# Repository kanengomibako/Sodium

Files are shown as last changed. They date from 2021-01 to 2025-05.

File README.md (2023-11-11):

# Sodium
### STM32 Programmable Digital Effects Pedal
STM32マイコンを搭載した、プログラミング可能なデジタルエフェクターです。C言語またはC++で開発を行います。もちろんプログラム書き込み後は単体のエフェクターとして動作可能です。

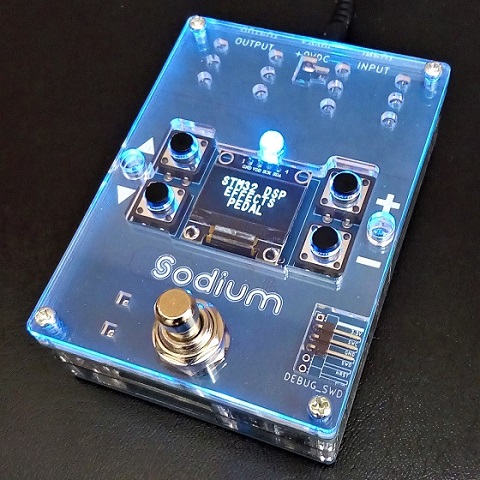
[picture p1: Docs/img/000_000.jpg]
Sodium_pic


### 別途必要なもの
- DC9V（センターマイナス）出力のACアダプターで、0.3A以上の電流出力が可能なもの
- PC（Windows、macOS、Linux いずれも可、64bit推奨）<br/>※ 32bit環境では使用できる開発ソフトが限られます。
- STM32対応のデバッガ（プログラム書き込みやデバッグを行う機器）<br/>
	→ [デバッガ購入について](Docs/005_デバッガ購入について.md)
- PCとデバッガを接続するUSBケーブル
- デバッガとSodium本体を接続するケーブル<br/>
	→ [コネクタ付コード 3P](https://akizukidenshi.com/catalog/g/gC-15384/) 等

### 各部の機能
- INPUT 端子：ギターや他の機器からの出力を接続します。
- OUTPUT 端子：アンプや他の機器の入力へ接続します。
- +9VDC 端子：ACアダプターを接続します。
- 各スイッチ：任意の機能をプログラミング可能です。初期プログラムの操作については[別ページ](Docs/000_初期プログラムについて.md)をご参照ください。
- Serial Wire Debug (SWD)接続ピン：デバッガのSWCLK、GND、SWDIOピンを、SodiumのSWC、GND、SWDピンへそれぞれ接続します。

### 資料
- [Rev.E 基板（2021年5月以降販売分）での主な変更点](Docs/006_Rev.E基板での主な変更点.md)
- [初期プログラムについて](Docs/000_初期プログラムについて.md)
- [デバッガ購入について](Docs/005_デバッガ購入について.md)
- [プログラム書き込み・デバッグ](Docs/001_プログラム書き込み・デバッグ.md)
- [サンプルプログラムについて](Docs/002_サンプルプログラムについて.md)
- [マイコンの機能設定](Docs/003_マイコンの機能設定.md)
- [プログラミング概要](Docs/004_プログラミング概要.md)
- [エフェクト種類管理（fx.cpp）について](Docs/100_エフェクト種類管理（fx.cpp）について.md)
- [エフェクトファイル（fx_○○.hpp）について](Docs/110_エフェクトファイル（fx_○○.hpp）について.md)
- [各エフェクト説明目次](Docs/200_各エフェクト説明目次.md)

| 主な仕様 |  |
| - | - |
| サンプリング周波数 | 44.1 kHz（48 kHz または 96 kHz に設定可能） |
| 内部演算 | 32ビット浮動小数点 |
| AD、DA変換 | 24 ビット |
| レイテンシ | 1.5 ミリ秒（初期プログラム実行時） |
| 最大入力レベル | 1.0 Vrms (+2.2 dBu) |
| 入力インピーダンス | 1 MΩ |
| 最大出力レベル | 1.35 Vrms (+4.8 dBu) |
| 出力インピーダンス | 1 kΩ |
| バイパス | バッファード・バイパス（バイパス音もAD/DA変換されます） |
| コントロール | 押しボタンスイッチ×4　フットスイッチ×1 |
| ディスプレイ | 有機ELディスプレイ　モノクロ128×64ドット |
| インジケーター | 3色LED（直径5mm） |
| 接続端子 | INPUT端子　OUTPUT端子　電源入力端子<br/>Serial Wire Debug (SWD)接続ピン |
| 消費電流 | 150 mA |
| 外形寸法 | 幅 73 mm × 奥行 107 mm × 高さ 46 mm<br/>（フットスイッチ部を除いた高さ 33 mm）<br/>※ 2021年1月販売分は高さ+2mm |
| 質量 | 240 g |

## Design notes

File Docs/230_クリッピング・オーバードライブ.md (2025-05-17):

# クリッピング・オーバードライブ

歪み系エフェクトに使うクリッピングについて、下記記事にまとめています。

- [歪みと波形・倍音その9（非線形性と歪み）](https://kanengomibako.github.io/pages/00209.html)

クリッピングに使いやすそうな関数を下図にまとめました。歪み始めや頭打ち部分の音量がそれぞれ違ってくるため、似たような形になるように適宜調整しています。（[GeoGebra](https://www.geogebra.org/) で作成）

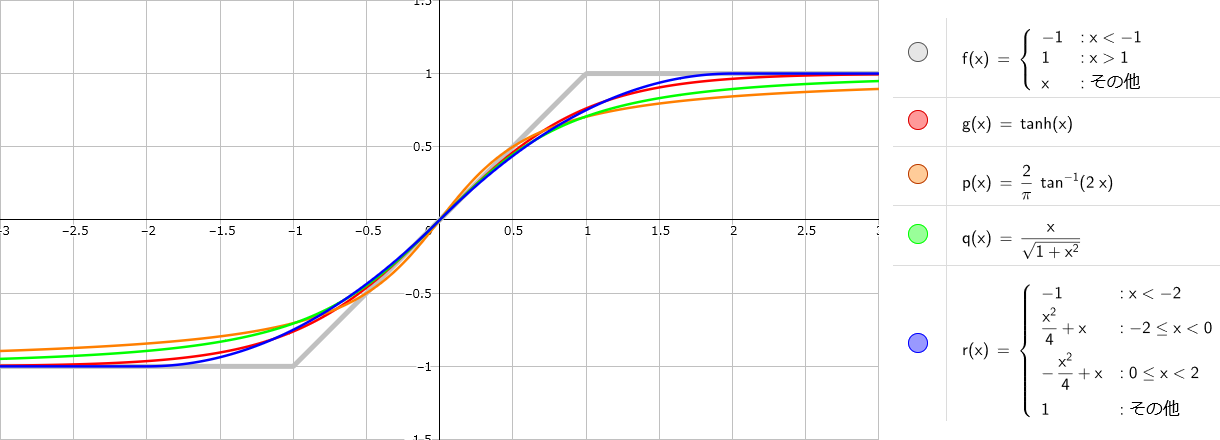
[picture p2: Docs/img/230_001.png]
graph


下記参考ページでは、tanh 関数を変形させた例が記載されています。

- [gDSP](http://gdsp.hf.ntnu.no/) - [The modified tanh() function](http://gdsp.hf.ntnu.no/lessons/3/18/)

---

[fx_overdrive.hpp](https://github.com/kanengomibako/Sodium/blob/main/Src/example/fx_overdrive.hpp) （オーバードライブ）のコード内容について説明します。

```c++
private:
  const string name = "OVERDRIVE";
  const uint16_t color = COLOR_RG; // 赤緑
  const string paramName[20] = {"LEVEL", "GAIN", "TREBLE", "BASS"};
  enum paramName {LEVEL, GAIN, TREBLE, BASS};
  float param[20] = {1, 1, 1, 1};
  const int16_t paramMax[20] = {100,100,100,100};
  const int16_t paramMin[20] = {  0,  0,  0,  0};
  const uint8_t paramNumMax = 4;

  signalSw bypass;
  hpf hpfFixed, hpfBass; // 出力ローカット、入力BASS調整
  lpf lpfFixed, lpfTreble; // 入力ハイカット、出力TREBLE調整
```
コントロールは全て0～100としました。下部で固定値のフィルタとトーン調整用フィルタを準備しています。<br>
<br>

```c++
  virtual void setParam()
  {
    static uint8_t count = 0;
    count = (count + 1) % 10; // 負荷軽減のためパラメータ計算を分散させる
    switch(count)
    {
      case 0:
        param[LEVEL] = logPot(fxParam[LEVEL], -50.0f, 0.0f);  // LEVEL -50～0 dB
        break;
      case 1:
        param[GAIN] = logPot(fxParam[GAIN], 20.0f, 60.0f); // GAIN 20～60 dB
        break;
      case 2:
        param[TREBLE] = 10000.0f * logPot(fxParam[TREBLE], -30.0f, 0.0f); // TREBLE LPF 320～10k Hz
        break;
      case 3:
        param[BASS] = 2000.0f * logPot(fxParam[BASS], 0.0f, -20.0f); // BASS HPF 200～2000 Hz
        break;
      case 4:
        lpfTreble.set(param[TREBLE]);
        break;
      case 5:
        hpfBass.set(param[BASS]);
        break;
      case 6:
        lpfFixed.set(4000.0f); // 入力ハイカット 固定値
        break;
      case 7:
        hpfFixed.set(30.0f); // 出力ローカット 固定値
        break;
      default:
        break;
    }
  }
```
`logPot`関数は [lib_calc.hpp](https://github.com/kanengomibako/Sodium/blob/main/Src/example/lib_calc.hpp) にある通り、パラメータ整数値 0 ～ 100 を dB 倍率へ変換します。この関数はゲインだけでなく、フィルタの周波数についても調整しやすいです。上記`BASS`のハイパスフィルタ周波数の場合は 0 dB（1倍）～ -20 dB（0.1倍）で計算され、2000 ～ 200 Hz で変化するという具合です。

固定値のフィルタ周波数設定（`set`）は何度も実行する必要はないため、`init`関数内に記載しても問題ありません。<br>
<br>

```c++
  virtual void process(float xL[], float xR[])
  {
    setParam();

    for (uint16_t i = 0; i < BLOCK_SIZE; i++)
    {
      float fxL = xL[i];

      fxL = hpfBass.process(fxL);   // 入力ローカット BASS
      fxL = lpfFixed.process(fxL);  // 入力ハイカット 固定値
      fxL = param[GAIN] * fxL;      // GAIN
      fxL = atanf(fxL + 0.5f);      // arctanによるクリッピング、非対称化
      fxL = hpfFixed.process(fxL);  // 出力ローカット 固定値 直流カット
      fxL = lpfTreble.process(fxL); // 出力ハイカット TREBLE
      fxL = param[LEVEL] * fxL;     // LEVEL

      xL[i] = bypass.process(xL[i], fxL, fxOn);
    }
  }
```
HPF → LPF → GAIN → クリッピング → HPF → LPF → LEVEL という流れです。クリッピングは直流成分を加えて非対称としましたが、直流成分を増幅しないように、直後にハイパスフィルタを入れます。

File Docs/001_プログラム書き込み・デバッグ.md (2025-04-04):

# プログラム書き込み、デバッグ

例として、初期プログラムの書き込み、デバッグまでの手順を説明します。

***

### 1. STM32CubeIDEのインストール
STM32マイコンの統合開発環境として、[STM32CubeIDE](https://www.st.com/ja/development-tools/stm32cubeide.html)をインストールします（32bitのOSには非対応）。ダウンロードに[myST](https://www.st.com/content/st_com/ja.html)への登録が必要です。初回起動時にWorkspace（作業フォルダ）を設定しますが、パスに全角文字が入らないようにしておきます。STM32CubeIDE未経験の方は、練習としてNucleo Boardを使ったLチカを先にされておくことをお勧めします。

- 参考ページ → [STM32 Nucleo STM32F303K8でLチカ & STM32CubeIDEで開発](https://ameblo.jp/denshi-1996/entry-12806626635.html)

***

### 2. 新規プロジェクト作成
- STM32CubeIDEを起動、File → New → STM32 Project
- Part Number に「F722RC」と入力 → STM32F722RC を選択 → Next（※ [Rev.E 基板](006_Rev.E基板での主な変更点.md)の場合、F722RE）
- Project Name に「Sodium_test」と入力 → Finish
- 自動で開かれる Sodium_test.ioc は閉じる

※ 初回はデータのダウンロード等があるため時間がかかります。

***

### 3. 必要なファイルのダウンロード
下記URLからzipファイルをダウンロード・展開し、出てきた8つのファイルを移動させます。
- [https://github.com/kanengomibako/Sodium/raw/main/Src/test/Sodium_test.zip](https://github.com/kanengomibako/Sodium/raw/main/Src/test/Sodium_test.zip)

	- Sodium_test.ioc → プロジェクトフォルダ内の同名ファイルに上書き
	- main.c → Core/Src フォルダ内の同名ファイルに上書き
	- user_main.c　fonts.c　ssd1306.c → Core/Src フォルダへ
	- user_main.h　fonts.h　ssd1306.h → Core/Inc フォルダへ

ディスプレイ用ライブラリは下記リポジトリのものを利用しています。
- [https://github.com/4ilo/ssd1306-stm32HAL](https://github.com/4ilo/ssd1306-stm32HAL)

***

### 4. コード出力、ビルド
- Sodium_test.ioc を開き、歯車アイコンをクリックしてコード出力

※ バージョンが違うといったメッセージが表示された場合は、「Migrate」を選択します。

- 金槌アイコンをクリックしてビルド開始

***

### 5. デバッガの接続、デバッグ
- デバッガのSWCLK、GND、SWDIOピンを、SodiumのSWC、GND、SWDピンへそれぞれ接続

▼ Nucleo Board（Nucleo-64タイプ）を使う場合（左上のジャンパーを外しておく）
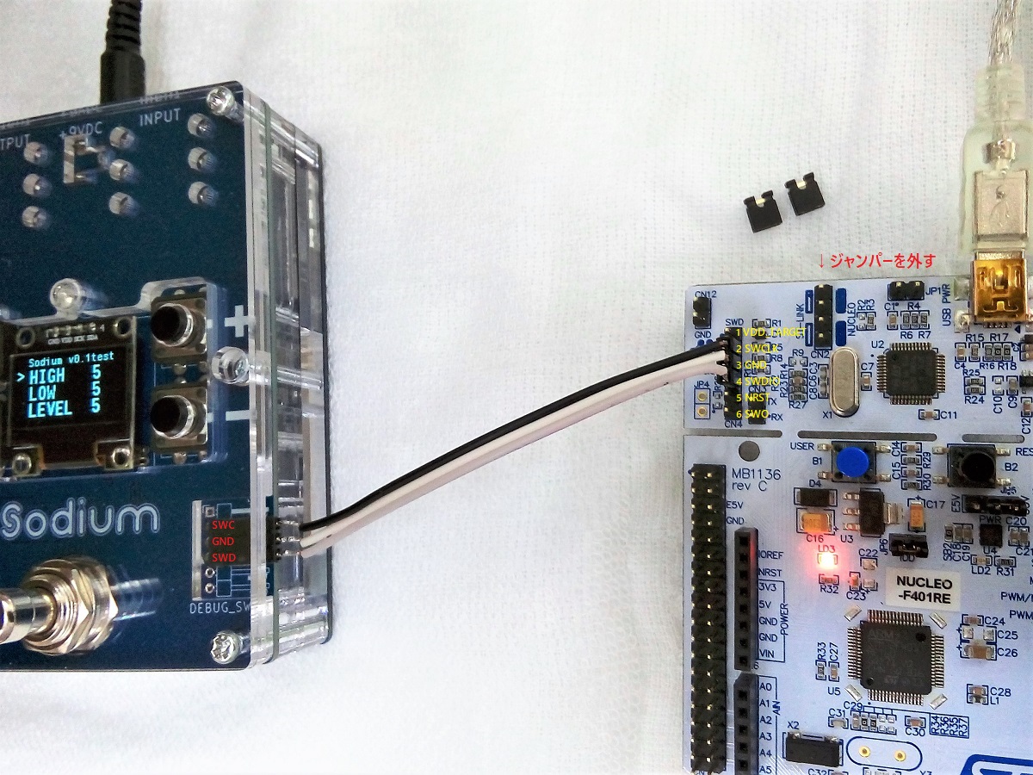
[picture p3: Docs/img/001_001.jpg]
デバッガーの接続
  

- 虫アイコンをクリック → 設定ウィンドウが2種類出てくるが、両方ともそのままOK

プログラムが書き込まれ、デバッグが開始されます。デバッグ画面では動作開始、一時停止等の操作を行うことができます。

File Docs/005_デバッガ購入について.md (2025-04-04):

# デバッガ購入について

### [Nucleo Board](https://www.st.com/ja/evaluation-tools/stm32-nucleo-boards.html)

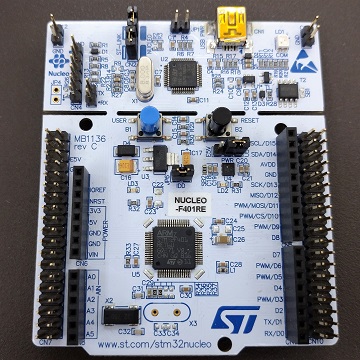
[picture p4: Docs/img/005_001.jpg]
Nucleo
 

STマイクロの低価格なマイコンボードです。デバッガが上部についており、切り込み部分から切り離して使うこともできます。様々な種類がありますが、安いもので問題ありません（USBコネクターの種類に注意）。他にもデバッガとして使えるものに[Discovery Kit](https://jp.rs-online.com/web/p/microcontroller-development-tools/7587554)、[STLINK-V3MINIE](https://akizukidenshi.com/catalog/g/g118187/)、[ST-LINK/V2](https://jp.rs-online.com/web/p/chip-programmers/7141701)、[STLINK-V3SET](https://akizukidenshi.com/catalog/g/gM-14361/)があります。

＜参考価格＞（2025年4月4日時点）

秋月電子へのリンクですが、RSコンポーネンツ等でも購入できます。

[NUCLEO-F103RB](https://akizukidenshi.com/catalog/g/g107724/) ￥2,200　[コネクター付コード 3P](https://akizukidenshi.com/catalog/g/gC-15384/) ￥60　[両端ロングピンヘッダー 1×6](https://akizukidenshi.com/catalog/g/g109055/) ￥20　[USBケーブル Type-Aオス⇔ミニBオス 1.5m](https://akizukidenshi.com/catalog/g/g117014/) ￥100

---

### ST-LINK V2 互換品

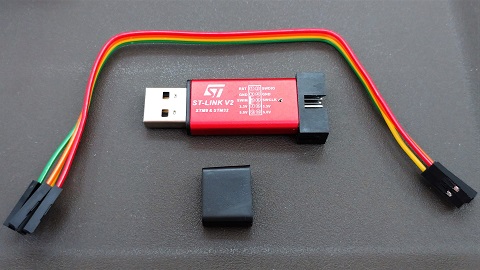
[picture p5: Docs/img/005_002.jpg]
stlc
 

AmazonやAliExpressで販売されている、低価格でコンパクトなST-LINK互換品です。~~十数個買ってみましたが特に問題なく使えたので、とにかく安く済ませたい場合はこちらで大丈夫だと思います。~~**最新のSTM32CubeIDE（1.13.2）ではファームウェアのアップグレードができず、使えなくなりました。内蔵マイコンの種類によってはアップグレードできるものがありますが、購入しない方が無難です。

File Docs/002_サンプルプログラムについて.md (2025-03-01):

# サンプルプログラムについて

サンプルプログラムの導入手順と操作方法を説明します。

※ 予期せぬエラーが発生する可能性があります。音量に充分注意して下さい。

（STM32CubeIDEのバージョン：1.17.0）

***

### 1. STM32CubeIDE 新規プロジェクト作成
- STM32CubeIDEを起動、File → New → STM32 Project
- Part Number に「F722RC」と入力 → STM32F722RC を選択 → Next（※ [Rev.E 基板](006_Rev.E基板での主な変更点.md)の場合、F722RE）
- Project Name に「Sodium_example」と入力
- Targeted Language に C++ を選択 → Finish
- 自動で開かれる Sodium_example.ioc は閉じる

***

### 2. 必要なファイルのダウンロード
下記URLからzipファイルをダウンロード・展開し、出てきたファイルを移動させます。
- [https://github.com/kanengomibako/Sodium/raw/main/Src/example/Sodium_example_v1.9.zip](https://github.com/kanengomibako/Sodium/raw/main/Src/example/Sodium_example_v1.9.zip)
	- Sodium_example.ioc　STM32F722RCTX_FLASH.ld → プロジェクトフォルダ内の同名ファイルに上書き（※ [Rev.E 基板](006_Rev.E基板での主な変更点.md)の場合、STM32F722RETX_FLASH.ld）
		- Sodium_example.ioc を開き、歯車アイコンをクリックしてコード出力	
	- .cファイル　.cppファイル → Core/Src フォルダへ（ main.c は上書き）
	- .hファイル　.hppファイル → Core/Inc フォルダへ
- ビルドして書き込みを行うと、数種類のエフェクトが入ったプログラムが実行できます。
- common.h を編集すると各種機能や時間設定等を行うことができます。
- fx.cpp を編集すると有効化するエフェクトを選択できます。

***

### 3. 操作方法
- 左上スイッチ（▲）
	- 短押し：カーソルを前へ移動
	- 長押し：エフェクト切替
	- 左下スイッチと同時に長押し：現在選択しているエフェクトのパラメータを保存
- 左下スイッチ（▼）
	- 短押し：カーソルを次へ移動
	- 長押し：エフェクト切替
	- 左上スイッチと同時に長押し：現在選択しているエフェクトのパラメータを保存
- 右上スイッチ（＋）
	- 短押し：パラメータ増加
	- 長押し：パラメータを10ずつ増加
	- 右下スイッチと同時に短押し：パラメータを最大値と最小値の中間の値へ変更
	- 左上スイッチと同時に短押し：パラメータを最大値へ変更
- 右下スイッチ（ー）
	- 短押し：パラメータ減少
	- 長押し：パラメータを10ずつ減少
	- 右上スイッチと同時に短押し：パラメータを最大値と最小値の中間の値へ変更
	- 左下スイッチと同時に短押し：パラメータを最小値へ変更
- フットスイッチ
	- 短押し：エフェクトのオン／オフ切替（オン時LED点灯）
	- 長押し：タップテンポモードへ、さらに長く押したままにするとチューナーモードへ（もう一度長押しで通常モードに戻る）
- その他
	- 保存データ全消去：左上スイッチ・右下スイッチ・フットスイッチを押しながら起動

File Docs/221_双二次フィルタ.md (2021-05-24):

# 双二次フィルタ

双二次フィルタ（BiQuad フィルタ）はデジタルフィルタの中で特に使いやすいフィルタです。イコライザやローパスフィルタ、ハイシェルフフィルタ等、様々なタイプのフィルタを使うことができます。入力と出力の関係は次の式で表されます。

- y<sub>n</sub> = (b<sub>0</sub>/a<sub>0</sub>) x<sub>n</sub> + (b<sub>1</sub>/a<sub>0</sub>) x<sub>n-1</sub> + (b2/a<sub>0</sub>) x<sub>n-2</sub> - (a<sub>1</sub>/a<sub>0</sub>) y<sub>n-1</sub> - (a<sub>2</sub>/a<sub>0</sub>) y<sub>n-2</sub>

[1次フィルタ](220_1次ローパス・ハイパスフィルタ.md)の時と同様に、前回・前々回の入出力データを使います。フィルタのタイプに応じて係数 a<sub>1</sub>、b<sub>1</sub> 等の計算式が変わります。

【参考ページ】
- [C++でVST作り](https://vstcpp.wpblog.jp/) - [簡単なデジタルフィルタの実装](https://vstcpp.wpblog.jp/?page_id=523)
	
	周波数特性の図もあり、非常に素晴らしいサイトです。
---

[lib_filter.hpp](https://github.com/kanengomibako/Sodium/blob/main/Src/example/lib_filter.hpp) のコード内容について説明します。

- 三角関数等の計算

```c++
inline float bqSinOmega(float fc)
{
//（中略）
}

inline float bqCosOmega(float fc)
{
//（以下略）
```
3次関数の近似式を使用しています。sinf 関数より少し速い程度です。<br>
<br>

- フィルタタイプ
```c++
enum BQFtype
{
  OFF, // No Filter (default)
//（中略）
  APF, // All Pass Filter
};
```
各フィルタタイプの定義です。後々出てくる係数設定の場合分けに使用します。<br>
<br>

- 実行
```c++
  float process(float x) // BiQuadフィルタ 実行
  {
    float y = b0 * x + b1 * x1 + b2 * x2 - a1 * y1 - a2 * y2;
    x2 = x1;
    x1 = x;
    y2 = y1;
    y1 = y;
    return y;
  }
```
`a0` が式に入っていないのは、係数計算の時に `b0` 等に含めて計算しているためです。`x1`、`x2`、`y1`、`y2` に過去のデータを保存しておき、次回呼び出し時の計算で使用します。<br>
<br>

- 係数設定
```c++
  void setCoef(int type, float fc, float q_bw, float gain) // 係数設定
  {
    switch(type)
    {
    case PF:
      setPF(fc, q_bw, gain);
      break;
//（中略）
    }
  }

  // 各フィルタタイプ 係数設定
  void setPF(float fc, float q, float gain)
  {
    float alpha = bqAlphaQ(fc,q);
    float cos = bqCosOmega(fc);
    float A = bqA(gain);

    float norm = 1.0f / (1.0f + alpha / A);
    a1 = (-2.0f * cos) * norm;
    a2 = ( 1.0f - alpha / A) * norm;
    b0 = ( 1.0f + alpha * A) * norm;
    b1 = a1;
    b2 = ( 1.0f - alpha * A) * norm;
  }
//（以下略）
```
フィルタのタイプを自由に変更したい場合、`setCoef`関数でタイプ別に係数設定を行えます（通常はタイプ固定で`setPF`関数等を直接実行します）。`norm` は 1 /  a<sub>0</sub> にあたるもので、あらかじめ他の係数と一緒に計算しています。帯域幅（BW）を使うと計算負荷が重いため、全てQ値を使った設定です。<br>
<br>

---

[fx_filter.hpp](https://github.com/kanengomibako/Sodium/blob/main/Src/example/fx_filter.hpp) は、音量調整と双二次フィルタをかけるエフェクトです。コード内容について説明します。

```c++
private:
  const string name = "BQ FILTER";
  const uint16_t color = COLOR_BG; // 青緑
  const string paramName[20] = {"LV", "TYPE", "Fc", "Q", "dB"};
  enum paramName {LEVEL, TYPE, FREQ, Q, GAIN};
  float param[20] = {1, 1, 1, 1, 1};
  const int16_t paramMax[20] = { 20,  8,999, 99, 15};
  const int16_t paramMin[20] = {-20,  0,  2,  1,-15};
  const uint8_t paramNumMax = 5;

  const string typeName[9] = {"OFF","PF","LSF","HSF","LPF","HPF","BPF","NF","APF"};
  signalSw bypass;
  biquadFilter bqf1;
```
フィルタのタイプを変更できるようにし、タイプ名表示用に文字列`typeName`を準備しています。<br>
<br>

```c++
  virtual void setParam()
  {
    static uint8_t count = 0;
    count = (count + 1) % 10; // 負荷軽減のためパラメータ計算を分散させる
    switch(count)
    {
      case 0:
        param[LEVEL] = dbToGain(fxParam[LEVEL]); // LEVEL -20...+20 dB
        break;
      case 1:
        param[TYPE] = (float)fxParam[TYPE]; // フィルタタイプ
        break;
      case 2:
        param[FREQ] = (float)fxParam[FREQ] * 10.0f; // フィルタ 周波数 20...9990 Hz
        break;
      case 3:
        param[Q] = (float)fxParam[Q] * 0.1f; // フィルタ Q 0.1...9.9
        break;
      case 4:
        param[GAIN] = (float)fxParam[GAIN]; // フィルタ GAIN -15...+15 dB
        break;
      case 5:
        bqf1.setCoef(fxParam[TYPE], param[FREQ], param[Q], param[GAIN]); // フィルタ 係数設定
        break;
      default:
        break;
    }
  }
```
`setCoef`関数でタイプ別に係数設定を更新します。整数型が都合がよいため`param[TYPE]`ではなく`fxParam[TYPE]`の方を使っています。<br>
<br>

```c++
  virtual void process(float xL[], float xR[])
  {
    setParam();

    for (uint16_t i = 0; i < BLOCK_SIZE; i++)
    {
      float fxL = xL[i];
      fxL = bqf1.process(fxL); // フィルタ実行
      fxL = param[LEVEL] * fxL; // LEVEL
      xL[i] = bypass.process(xL[i], fxL, fxOn);
    }
  }
```
エフェクト用データ`fxL`に、`process`関数を実行します。

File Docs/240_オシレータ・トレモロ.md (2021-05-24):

# オシレータ・トレモロ

揺れ系エフェクトに使う LFO（Low Frequency Oscillator）の実装について説明します。下図は周波数 f（周期 1 / f ）、出力 0 ～ 1 ののこぎり波です。

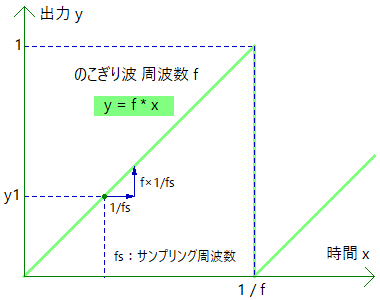
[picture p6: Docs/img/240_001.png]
graph
 

直線の傾きは 1 ÷ ( 1 / f ) で f となります。ある時点の出力 y1 から、次のサンプル時点までに経過する時間は 1 / fs です。増加する出力は傾き f × ( 1 / fs ) で f / fs となります。[lib_osc.hpp](https://github.com/kanengomibako/Sodium/blob/main/Src/example/lib_osc.hpp) の`sawWave`クラスでは下記コードです。

```c++
  float output()
  {
    float y = y1 + freq / SAMPLING_FREQ;
    if (y > 1) y = y - 1.0f;
    y1 = y; // 前回出力値を記録
    return y;
  }
```

前回の出力値を記録しておき、 f / fs を足して出力します。出力が 1 を超えた時点で 1 を引いてリセットします（0 にすると周期が少しズレてしまいます）。y1 の初期値を変更しておけば、位相を変えることができます。

正弦波と三角波（`sineWave`、`triangleWave`クラス）はのこぎり波を利用して実装しています。低い周波数だけでなく可聴域の音声信号も出力可能です。[fx_oscillator.hpp](https://github.com/kanengomibako/Sodium/blob/main/Src/example/fx_oscillator.hpp) はエフェクトではなく波形テスト用の発振器です。

---

[fx_tremolo.hpp](https://github.com/kanengomibako/Sodium/blob/main/Src/example/fx_tremolo.hpp) （トレモロ）のコード内容について説明します。

```c++
  virtual void setParam()
  {
    static uint8_t count = 0;
    count = (count + 1) % 10; // 負荷軽減のためパラメータ計算を分散させる
    switch(count)
    {
      case 0:
        param[LEVEL] = logPot(fxParam[LEVEL], -20.0f, 20.0f);  // LEVEL -20～20 dB
        break;
      case 1:
        param[RATE] = 0.01f * (105.0f - (float)fxParam[RATE]); // RATE 周期 1.05～0.05 秒
        break;
      case 2:
        param[DEPTH] = (float)fxParam[DEPTH] * 0.1f; // DEPTH -10～10 dB
        break;
      case 3:
        param[WAVE] = logPot(fxParam[WAVE], 0.0f, 50.0f); // WAVE 三角波～矩形波変形
        break;
      case 4:
        tri.set(1.0f / param[RATE]); // 三角波 周波数設定
        break;
      default:
        break;
    }
  }
```
三角波で音量を最大 ±10 dB 揺らします。WAVE コントロールは、揺れに使う波形を矩形波に変形させます。<br>
<br>

```c++
  virtual void process(float xL[], float xR[])
  {
    setParam();

    for (uint16_t i = 0; i < BLOCK_SIZE; i++)
    {
      float fxL = xL[i];

      float gain = 2.0f * tri.output() - 1.0f; // LFO -1～1 三角波
      gain = param[WAVE] * gain;     // 三角波を増幅
      if (gain > 1.0f) gain = 1.0f;  // クリッピング（矩形波に近い形へ）
      if (gain < -1.0f) gain = -1.0f;
      gain = param[DEPTH] * gain; // DEPTH -10～10 dB

      fxL = dbToGain(gain) * fxL; // 音量を揺らす
      fxL = param[LEVEL] * fxL;   // LEVEL

      xL[i] = bypass.process(xL[i], fxL, fxOn);
    }
  }
```
LFO の出力はわかりやすいように -1 ～ 1 の範囲としました。矩形波の音量変化が大きすぎる場合、「プチッ」というノイズが聞こえる場合があります。クリッピングに tanh 等の関数を用いてみるのもよいかもしれません。

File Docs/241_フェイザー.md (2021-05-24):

# フェイザー

位相を変化させた音と原音を足し合わせると、特定の周波数が減衰し谷となるノッチフィルタのような特性が得られます。この谷の周波数を揺らすエフェクトがフェイザーです。位相を変化させるには、オールパスフィルタ（APF）を使用します。APF の数 2 個につき谷の数は 1 個となります。

---

[fx_phaser.hpp](https://github.com/kanengomibako/Sodium/blob/main/Src/example/fx_phaser.hpp) （フェイザー）のコード内容について説明します。[フィルタ](220_1次ローパス・ハイパスフィルタ.md)と [LFO](240_オシレータ・トレモロ.md) の組み合わせです。

```c++
private:
  const string name = "PHASER";
  const uint16_t color = COLOR_R; // 赤
  const string paramName[20] = {"LEVEL", "RATE", "STAGE"};
  enum paramName {LEVEL, RATE, STAGE};
  float param[20] = {1, 1, 1};
  const int16_t paramMax[20] = {100,100,  6};
  const int16_t paramMin[20] = {  0,  0,  1};
  const uint8_t paramNumMax = 3;

  signalSw bypass;
  triangleWave tri;
  apf apfx[12];
```
STAGE（段数）パラメータでフィルタの個数を変更できるようにします。APF は for ループで使用するため、配列でインスタンス生成しています（下記コード参照）。<br>
<br>

```c++
  virtual void process(float xL[], float xR[])
  {
    setParam();

    for (uint16_t i = 0; i < BLOCK_SIZE; i++)
    {
      float fxL = xL[i];

      float lfo = 20.0f * tri.output();    // LFO 0～20 三角波
      float freq = 200.0f * dbToGain(lfo); // APF周波数 200～2000Hz 指数的変化

      for (uint8_t j = 0; j < (uint8_t)param[STAGE]; j++) // 段数分APF繰り返し
      {
        apfx[j].set(freq);          // APF周波数設定
        fxL = apfx[j].process(fxL); // APF実行
      }

      fxL = 0.7f * (xL[i] + fxL); // 原音ミックス、音量調整
      fxL = param[LEVEL] * fxL;   // LEVEL

      xL[i] = bypass.process(xL[i], fxL, fxOn);
    }
  }
```
周波数は指数関数的変化がよいため、`dbToGain`を使いました。for ループを使って繰り返し APF をかけ、原音ミックスします。音量は LEVEL 50 でエフェクトオフと同じくらいになるよう調整しています。

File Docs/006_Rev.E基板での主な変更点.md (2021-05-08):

# Rev.E 基板での主な変更点

2021年5月販売分より、基板のバージョンが Rev.D → Rev.E となっています。

▼ OUTPUTジャック側から中を除くと、「Rev.E」の文字が見えます。

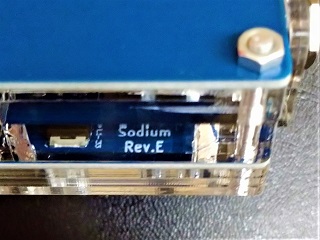
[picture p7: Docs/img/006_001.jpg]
E
 

---

- ### F722R"C" → F722R"E"

	入手性の問題から、マイコンが STM32F722RCT6 → STM32F722RET6 となり、フラッシュメモリの容量が 256 kB から 512 kB へ増えました。他の説明文書内の F722RC という記述は、適宜 F722RE に読み替えていただくようお願いします。互換性維持のため、STM32F722RETX_FLASH.ld ファイル内ではセクタ5以降の全領域をデータ保存用として設定してあります。
	
	※ 誤って F722RC のプログラムをそのまま書き込んでも動作に問題はありません。

---

- ### 赤LED 接続ピン追加

	赤LED をマイコンの PA7 ピンに接続しています。PWM を利用して明るさを調整する場合は、PA7 ピンが使えます。従来通り PA4 ピンにも接続したままなので、旧基板用プログラムの互換性についての問題はありません。

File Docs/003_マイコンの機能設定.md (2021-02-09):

# マイコンの機能設定

iocファイルを開くと、STM32マイコンのピンや機能の設定を行うことができます。Sodiumでの設定内容について説明します。

***

### 1. システム
- 処理高速化のためARTアクセラレータ、Dキャッシュを有効化
	- System Core → CORTEX_M7 → Cortex Interface Settings
		- ART ACCELERATOR : Enabled
		- CPU DCache : Enabled
- クロック源として外部水晶振動子を使用
	- System Core → RCC → High Speed Clock (HSE) [Crystal/Ceramic Resonator]
- デバッガ接続
	- System Core → SYS → Debug [Serial Wire]

***

### 2. OLEDディスプレイ接続（I2C）

- I2C1を有効化
	- Connectivity → I2C1 → I2C [I2C]
	- Parameter Settings タブ → I2C Speed Mode [Fast Mode]
	- PB6、PB7 を使うようにピン設定
	
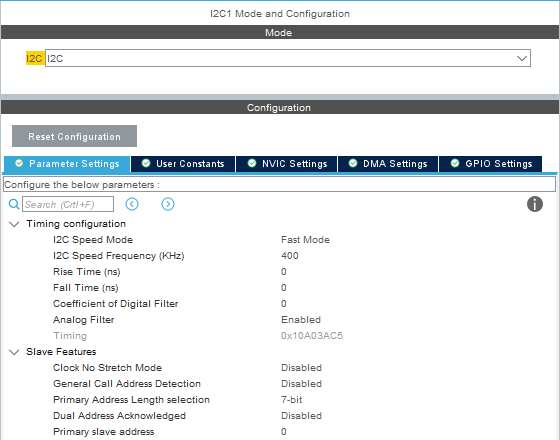
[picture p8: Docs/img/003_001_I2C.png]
I2C1
	 

***

### 3. オーディオコーデック接続（I2S）
- I2S2を有効化
	- Multimedia → I2S2 → MODE → Mode [Half-Duplex Master]　Master Clock Output にチェック
	- Parameter Settings タブ
		- Data and Frame Format [32 Bits Data on 32 Bits Frame]
		- Selected Audio Frequency [44 KHz]
		
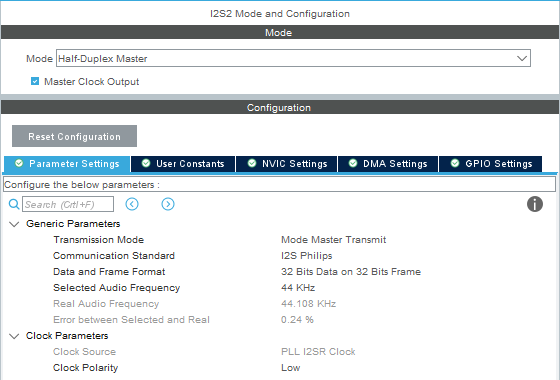
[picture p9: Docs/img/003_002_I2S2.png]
I2S2
		 
		
	- DMA Settings タブ → Addボタンで追加 → DMA Request [SPI2_TX]  Priority [Very High]
		- Mode : Circular
		- Data Width (Peripheral) : Half Word
		- Data Width (Memory) : Half Word
		
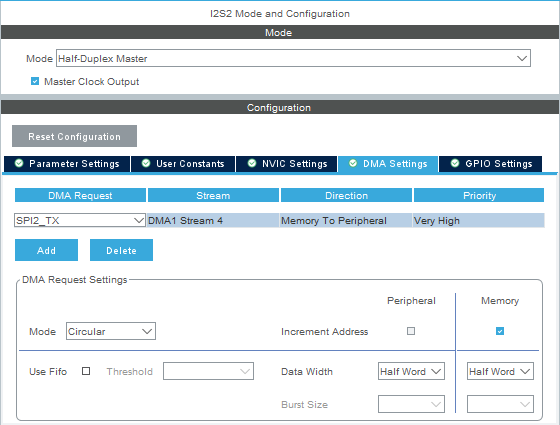
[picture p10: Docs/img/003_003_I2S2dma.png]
I2S2dma
		 
		
	- PB12、PB13、PB15、PC6 を使うようにピン設定
- I2S3を有効化
	- Multimedia → I2S3 → MODE → Mode [Half-Duplex Slave]
	- Parameter Settings タブ
		- Transmission Mode [Mode Slave Receive]
		- Data and Frame Format [32 Bits Data on 32 Bits Frame]
		- Selected Audio Frequency [44 KHz]
		
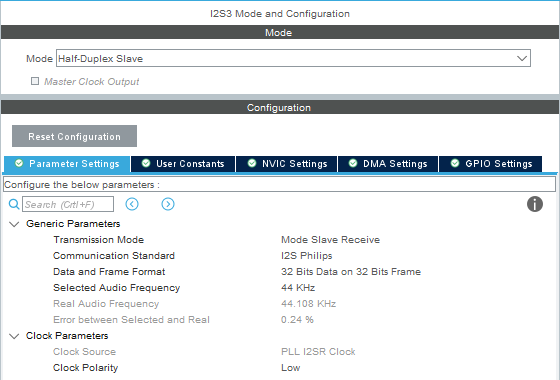
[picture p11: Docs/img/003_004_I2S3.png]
I2S3
		 
		
	- DMA Settings タブ → Addボタンで追加 → DMA Request [SPI3_RX]  Priority [Very High]
		- Mode : Circular
		- Data Width (Peripheral) : Half Word
		- Data Width (Memory) : Half Word
		
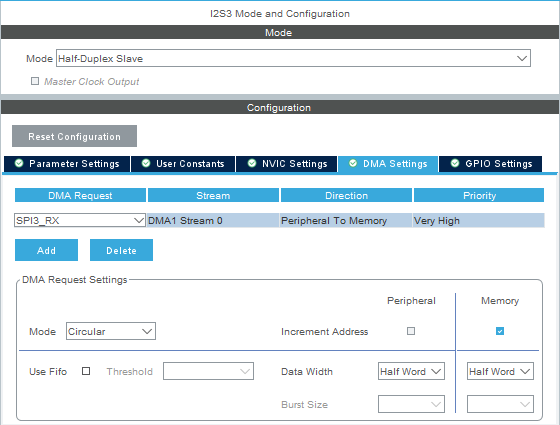
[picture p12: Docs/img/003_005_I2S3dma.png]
I2S3dma
		 
		
	- PA15、PC10、PC12 を使うようにピン設定

***

### 4. クロック
- Clock Configration タブで下図の通り設定

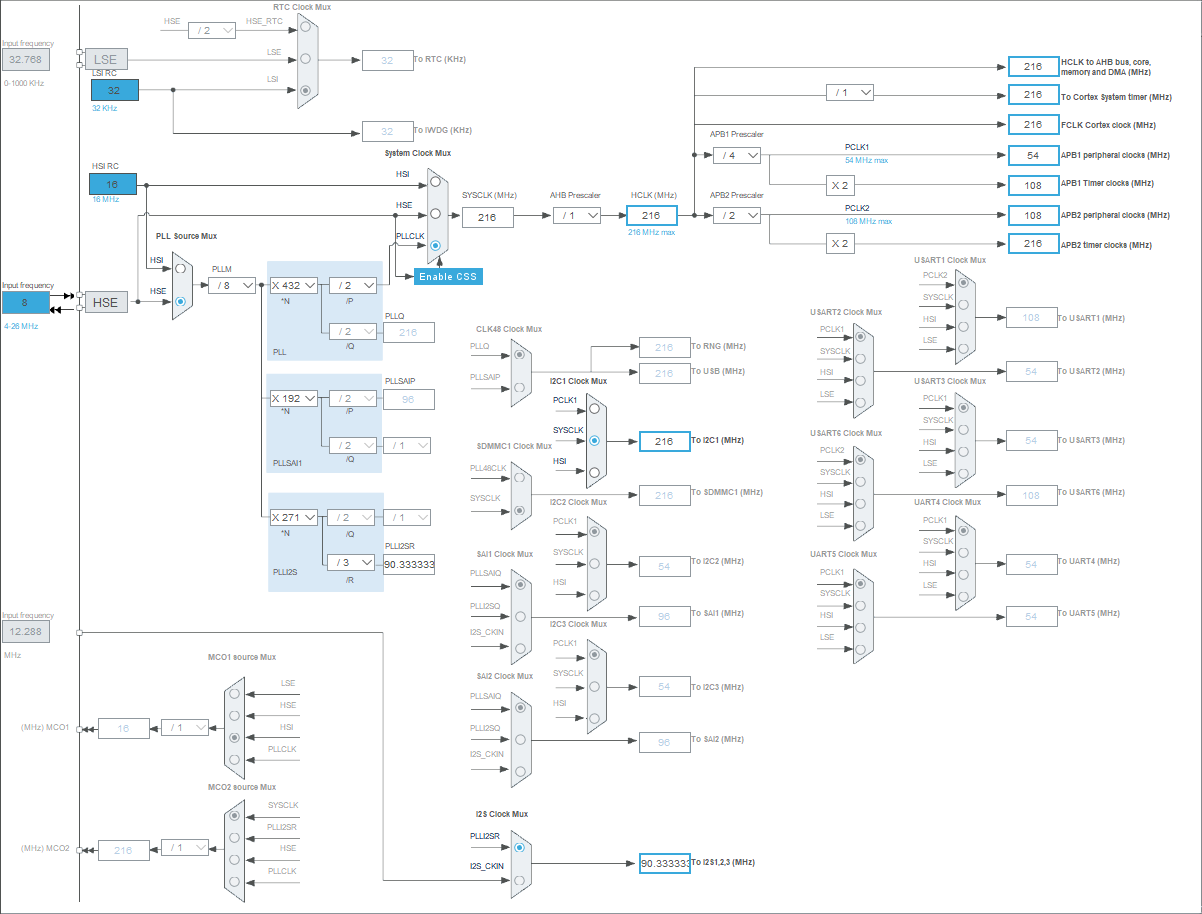
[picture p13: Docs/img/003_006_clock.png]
clock
 

実際のオーディオサンプリングレートは、I2Sクロックを2の累乗数で割った数となるため、90.333 MHz ÷ 2048 ＝ 44108.07 Hz です。44.1kHzから少しズレますが、プログラム上の定義をこの値にすれば実用上問題はありません（#define SAMPLING_FREQ 44108.07f）。

オーディオサンプリングレートを48kHzや96kHzにする場合は、PLLI2Sを [×295] [/3] とすると誤差が少ないです（98.333 MHz ÷ 2048 ＝ 48014.32 Hz）。

***

### 5. スイッチ・LED（GPIO）
- Pinout viewで入力ピン（PA1、PB0、PB1、PB4、PB5）、出力ピン（PA4、PA5、PA6、PB11）を設定

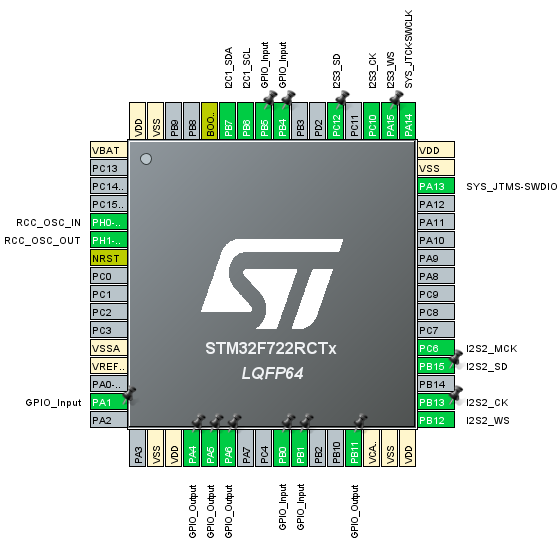
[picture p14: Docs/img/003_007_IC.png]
IC
 

- System Core → GPIO から入力ピンのプルアップとユーザーラベルを設定

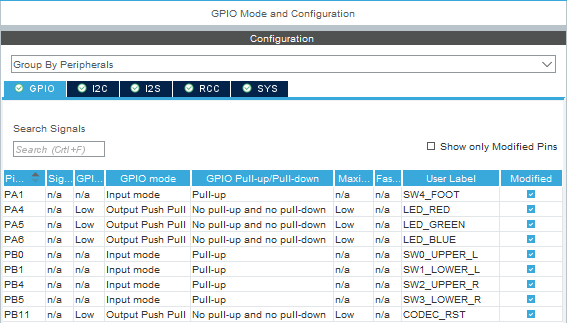
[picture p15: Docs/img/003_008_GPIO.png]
GPIO
 

ユーザーラベルを入力しておくと、main.h に定義が自動出力されます。（例：#define SW4_FOOT_Pin GPIO_PIN_1）

- ユーザーラベル一覧 
	- PA1	SW4_FOOT
	- PA4	LED_RED
	- PA5	LED_GREEN
	- PA6	LED_BLUE
	- PB0	SW0_UPPER_L
	- PB1	SW1_LOWER_L
	- PB4	SW2_UPPER_R
	- PB5	SW3_LOWER_R
	- PB11	CODEC_RST

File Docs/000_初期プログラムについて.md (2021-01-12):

# 初期プログラムについて

動作確認用初期プログラムとして、高音域・低音域・音量を調整するエフェクトが入っています。変更したパラメータを記憶する機能はありません。

### 起動時
ディスプレイが真っ白になり、LEDが赤、緑、青の順に点灯した後、エフェクト操作画面に切り替わります。

### スイッチ操作
- 左上スイッチ（▲）
	- 短押し：カーソル（＞）を上へ移動
	- 長押し：ディスプレイ上部に「SW0 LONG PUSH」と表示
- 左下スイッチ（▼）
	- 短押し：カーソル（＞）を下へ移動
	- 長押し：ディスプレイ上部に「SW1 LONG PUSH」と表示
- 右上スイッチ（＋）
	- 短押し：パラメータ増加
	- 長押し：ディスプレイ上部に「SW2 LONG PUSH」と表示
- 右下スイッチ（ー）
	- 短押し：パラメータ減少
	- 長押し：ディスプレイ上部に「SW3 LONG PUSH」と表示
- フットスイッチ
	- 短押し：エフェクトのオン／オフ切替（オン時青LED点灯）
	- 長押し：ディスプレイ上部に「SW4 LONG PUSH」と表示

### エフェクトオン時の動作
- HIGHを下げると、ローパスフィルタのカットオフ周波数が下がり（5k～500Hz）、高音域が減ります。
- LOWを下げると、ハイパスフィルタのカットオフ周波数が上がり（100～1kHz）、低音域が減ります。
- LEVEL調整で音量が変わります（-10dB～+10dB）。

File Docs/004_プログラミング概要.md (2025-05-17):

# プログラミング概要

### 1. ハードウェア
Sodiumの回路を簡略化した図を示します。

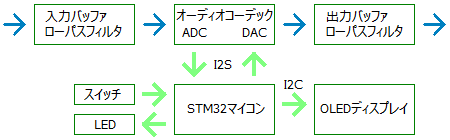
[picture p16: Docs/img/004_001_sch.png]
簡略図
 

入力信号は、オーディオコーデックでアナログ→デジタル変換され（ADC）、マイコンへ送られます。マイコンで信号処理し送られたデータは、デジタル→アナログ変換され（DAC）出力されます。このデータ送受信の方式は I2S（Inter-IC Sound）フォーマットと呼ばれるものとなっています。

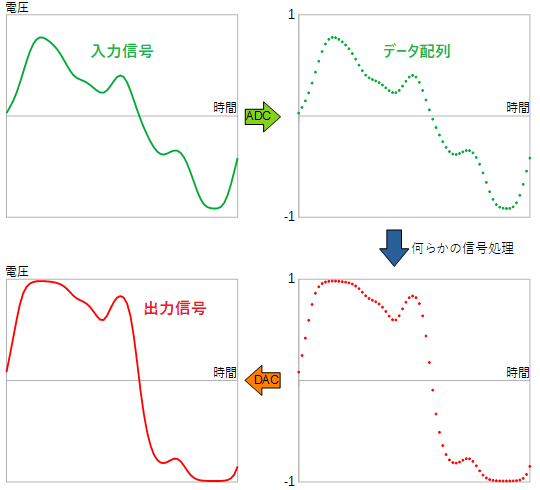
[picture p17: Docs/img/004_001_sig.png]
波形
 

機器に入力された音声信号は時間と電圧の関係として表されます。これを一定時間ごとにサンプリング（電圧読み取り）し、データ配列としてコンピュータに取り込みます。このサンプルデータに何らかの処理を施すことで、エフェクトをかけるということになります。

オーディオサンプリングレート44.1kHzの場合は、1秒間に44100個<sup>※</sup>のデータサンプルを送受信します。効率よく処理するため、ある程度まとまったサンプル数で処理を行います。このサンプルの個数がブロックサイズです。（※ 正確には、LchとRchで1組として44100組、88200個）

マイコンからディスプレイへのデータ送信はI2C（Inter-Integrated Circuit）と呼ばれる通信方式です。

***

### 2. 動作の流れ

- メインループ
	
	まず main.c の main 関数が実行されますが、その中で各機能の初期化後、mainLoop 関数が繰り返し実行されます。Sodiumでは、ここで主にディスプレイ表示の更新を行っています。
	※ main.c に直接主なコードを書いてもよいのですが、誤って USER CODE 以外の部分に書いてしまうとコード自動生成時に消去されるので、user_main.cpp という別ファイルに分けています。
	
- I2S 割り込み
	
	I2S通信で常にデータの入出力を行っていますが、ブロックサイズごとに割り込みが起こるようになっています（3. 信号処理詳細 参照）。この割り込み時にエフェクト処理やスイッチ状態の読み取りを行っています。

メインループ 

デュアルコアではないので、同時並行して処理を進めることはできません。基本は信号処理（割り込み）を行い、空いた時間にメインループの処理が進みます。もし信号処理に時間がかかりすぎれば、メインループ側の処理が進まないのでディスプレイ表示の更新がうまくいかないことになります。

***

### 3. 信号処理詳細

I2S用の送受信バッファ配列サイズはブロックサイズの4倍となっています。中身は「Lch前半・後半、Rch前半・後半」で、データの順序はLR交互（L・R・L・R...）ですが、ここではLRで1組として考えます。

データ前半の受信が終わると user_main.cpp にある HAL_I2S_RxHalfCpltCallback 関数が、後半の受信が終わると HAL_I2S_RxCpltCallback 関数が呼び出されます。下図のような流れです。

I2S 

例えば音量を上げるエフェクトの場合は、この割り込み内でデータ数値を増加させればいいということになります。

割り込みの間隔は、ブロックサイズ16、サンプリングレート44.1kHzの場合 16 / 44.1 = 0.36 ms（ミリ秒）です。処理遅延はこの2倍発生し、さらにオーディオコーデックIC自体の遅延があるため、全体の遅延（レイテンシ）は約1.5msとなっています。

- DMAについて

  DMA（Direct Memory Access）はデータ送受信の繰り返しを自動で行ってくれる便利な機能です。ただし転送は16ビット単位で、32ビットの場合上位と下位16ビットが入れ替わってしまうため、swap16 という関数を入れる処理を行っています。

***

### 4. スイッチ

前述の通り、I2S 割り込みは定期的に起こります。スイッチが押されているかどうかの読み取り（HAL_GPIO_ReadPin 関数）も割り込み内で行います。

読み取りはそこまで頻繁に行う必要はないため、割り込み1では左上スイッチ、割り込み2では左下スイッチ...というように読み取るスイッチを順番に入れ替えています。（フットスイッチはタップテンポの精度に関係してくるため、毎回読み取りを行っています。）

スイッチのチャタリングによる誤検出防止のため、数回連続で押されている判定があった場合に処理を行います。判定時間は #define SHORT_PUSH_MSEC 20 といった具合に設定しています。

***

### 5. データ保存

データ保存については下記記事にまとめています。

- [STM32 内蔵フラッシュメモリへのデータ保存](https://kanengomibako.github.io/pages/00250.html)

STM32F722RCT6の場合、データ保存先はセクタ5（開始アドレス 0x08020000）です。データ保存容量はもっと少なくてよいのですが、現状プログラムの容量が大きくないためそのままにしています。

フラッシュメモリは1万回以上書き換えできますが、プログラミングのミスで繰り返し書き込みが発生するような状態が起きると寿命が縮まってしまうため、注意が必要です。

***

### 6. 最適化設定

STM32CubeIDEで、コンパイラの最適化設定を高速動作向けに変更できます。
- Project → Properties → C/C++ Build → Settings → Tool Settings タブ
	- C言語
		- MCU GCC Compiler → Optimization → Optimization level [Optimize Most (-O3)]
	- C++
		- MCU G++ Compiler → Optimization → Optimization level [Optimize Most (-O3)]

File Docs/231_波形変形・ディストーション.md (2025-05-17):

# 波形変形・ディストーション

下記記事では真空管の特性を元に、波形を変形させる場合を考えています。

- [歪みと波形・倍音その10（真空管風デジタル歪み）](https://kanengomibako.github.io/pages/00210.html)

2次関数や指数関数等を使い、[クリッピング](230_クリッピング・オーバードライブ.md)とは違う歪みを生みだすということになります。

---

[fx_distortion.hpp](https://github.com/kanengomibako/Sodium/blob/main/Src/example/fx_distortion.hpp) （ディストーション）のコード内容について説明します。（[オーバードライブ](230_クリッピング・オーバードライブ.md)についても合わせてご参照ください。）

```c++
private:
  const string name = "DISTORTION";
  const uint16_t color = COLOR_R; // 赤
  const string paramName[20] = {"LEVEL", "GAIN", "TONE"};
  enum paramName {LEVEL, GAIN, TONE};
  float param[20] = {1, 1, 1};
  const int16_t paramMax[20] = {100,100,100};
  const int16_t paramMin[20] = {  0,  0,  0};
  const uint8_t paramNumMax = 3;

  signalSw bypass;
  hpf hpf1, hpf2, hpfTone; // ローカット1・2、トーン調整用
  lpf lpf1, lpf2, lpfTone; // ハイカット1・2、トーン調整用
```
TONE コントロールは、ハイパスフィルタを通した音とローパスフィルタを通した音をミックスする形式とします。ビッグマフ等で使われているタイプのトーンです。<br>
<br>

```c++
  virtual void setParam()
  {
    static uint8_t count = 0;
    count = (count + 1) % 10; // 負荷軽減のためパラメータ計算を分散させる
    switch(count)
    {
      case 0:
        param[LEVEL] = logPot(fxParam[LEVEL], -50.0f, 0.0f);  // LEVEL -50...0 dB
        break;
      case 1:
        param[GAIN] = logPot(fxParam[GAIN], 5.0f, 45.0f); // GAIN 5...+45 dB
        break;
      case 2:
        param[TONE] = mixPot(fxParam[TONE], -20.0f); // TONE 0～1 LPF側とHPF側をミックス
        break;
//（中略）
      case 8:
        hpfTone.set(1000.0f); // TONE用ローカット 固定値
        break;
      default:
        break;
    }
  }
```
`mixPot`関数は [lib_calc.hpp](https://github.com/kanengomibako/Sodium/blob/main/Src/example/lib_calc.hpp) にある通り、2つの信号を dB 計算を使った数値で加算します。片方を 0 ～ 1 の値で変化させ、1からその値を引いたものをもう一方の値とします（下記コード参照）。<br>
<br>

```c++
  virtual void process(float xL[], float xR[])
  {
    setParam();

    for (uint16_t i = 0; i < BLOCK_SIZE; i++)
    {
      float fxL = xL[i];
      fxL = hpf1.process(fxL); // ローカット1
      fxL = lpf1.process(fxL); // ハイカット1
      fxL = 10.0f * fxL; // 1段目固定ゲイン

      if (fxL < -0.5f) fxL = -0.25f; // 2次関数による波形の非対称変形
      else fxL = fxL * fxL + fxL;

      fxL = hpf2.process(fxL); // ローカット2 直流カット
      fxL = lpf2.process(fxL); // ハイカット2
      fxL = param[GAIN] * fxL; // GAIN

      fxL = tanhf(fxL); // tanhによる対称クリッピング

      fxL = param[TONE] * hpfTone.process(fxL)        // TONE
          + (1.0f - param[TONE]) * lpfTone.process(fxL); // LPF側とHPF側をミックス

      fxL = param[LEVEL] * fxL; // LEVEL

      xL[i] = bypass.process(xL[i], fxL, fxOn);
    }
  }
```
2段増幅構成で、フィルタの数も多くなっています。波形の非対称変形の後、直流成分を増幅しないようにハイパスフィルタを入れます。トーン回路の周波数は BOSS DS-1 風です。

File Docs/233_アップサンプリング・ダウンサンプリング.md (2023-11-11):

# アップサンプリング・ダウンサンプリング

ディストーション等のエフェクトでは、波形が歪みナイキスト周波数以上の高い周波数領域に倍音成分が発生することがあります。この時、ナイキスト周波数以下の低い周波数領域に折り返しノイズ（エイリアスノイズ）が発生します。この歪みを防ぐためには、アップサンプリング（オーバーサンプリング）してサンプリング周波数を上げる必要があります。

【参考ページ】
- [「言葉」でなく「心」で理解するエイリアスノイズとオーバーサンプリング](https://note.com/spmagnet8/n/n778a214a5898)

アップサンプリングするには、まずサンプルとサンプルの間に0を埋め込みサンプル数を増やします。そしてローパスフィルタ（LPF）をかけて信号を平滑化します。このLPFには通常FIRフィルタが使われます。

【参考ページ】
- [Introduction to Interpolation and Upsampling](https://www.wavewalkerdsp.com/2022/09/01/introduction-to-interpolation-and-upsampling/)

今回は処理を軽くするため、0の埋め込みではなく線形補間を使い、LPFには[双二次フィルタ](221_双二次フィルタ.md)を用いることとします。

アップサンプリングした後、ダウンサンプリングで元に戻します。この時、増やした分のサンプルを間引くことになりますが、折り返しノイズを防ぐため、余分な周波数成分を除去するLPFをかけておきます。

---

[lib_sampling.hpp](https://github.com/kanengomibako/Sodium/blob/main/Src/example/lib_sampling.hpp) 内のクラス`upsampling`のコード内容について説明します。

```c++
  void set(uint8_t n, float f)
  {
    m = n;
    fc = f;
    wpos = 0;
    lpf1.setLPF(fc / (float)m, 0.5411961f); // 4次Butterworth LPF 係数計算
    lpf2.setLPF(fc / (float)m, 1.3065630f);
  }
```
アップサンプリングの倍率、LPFの係数を設定します。ButterworthフィルタのQは[こちらのページ](https://www.earlevel.com/main/2016/09/29/cascading-filters/)で計算したものです。サンプリング周波数が`m`倍に上がっているため、カットオフ周波数は`1/m`にします。<br>
<br>

```c++
  void process(float x, float upsampleArray[], uint16_t sampleNum) // アップサンプリング用配列へ変換
  {
    for (uint16_t i = 0; i < m;)
    {
      upsampleArray[wpos] = lerp(x1, x, 1.0f/(float)m * (float)i); // サンプル間を線形補間
      i++;
      if (i == m) x1 = x; // 前回サンプル値x1を入れ替え
      if (fc > 1.0f && m > 1)
      { // アップサンプリング後の配列にLPFをかける
        upsampleArray[wpos] = lpf1.process(upsampleArray[wpos]);
        upsampleArray[wpos] = lpf2.process(upsampleArray[wpos]);
      }
      wpos++;
      if (wpos == sampleNum) wpos = 0; // 最大サンプル数(通常BLOCK_SIZE*m)までで0に戻す
    }
```
 [lib_calc.hpp](https://github.com/kanengomibako/Sodium/blob/main/Src/example/lib_calc.hpp) にある`lerp`関数でサンプルとサンプルの間を線形補間し、アップサンプリング用配列へ書き込みます。通常はブロックサイズ単位で処理するので、アップサンプリング用配列の要素数はブロックサイズ×アップサンプリングの倍率となります。LPFの影響で高音域が微妙に減少してしまうため、カットオフ周波数を0に設定してLPFをかけないようにすることも可能です。<br>
<br>

---

[lib_sampling.hpp](https://github.com/kanengomibako/Sodium/blob/main/Src/example/lib_sampling.hpp) 内のクラス`downsampling`のコード内容について説明します。

```c++
  void set(uint8_t n, float f)
  {
    m = n;
    fc = f;
    rpos = 0;
    lpf1.setLPF(fc / (float)m, 0.50979558f); // 8次Butterworth LPF 係数計算
    lpf2.setLPF(fc / (float)m, 0.60134489f);
    lpf3.setLPF(fc / (float)m, 0.89997622f);
    lpf4.setLPF(fc / (float)m, 2.56291540f);
  }
```
ダウンサンプリングの倍率、LPFの係数を設定します。折り返しノイズを防ぐためには急峻なフィルタが必要となるため、8次LPFとしています。<br>
<br>
```c++
  void process(float x, float downsampleArray[], uint16_t sampleNum) // ダウンサンプリング用配列へ変換
  {
    if (fc > 1.0f && m > 1)
    { // ダウンサンプリング前の配列にLPFをかける
      x = lpf1.process(x);
      x = lpf2.process(x);
      x = lpf3.process(x);
      x = lpf4.process(x);
    }
    if (rpos % m == 0) downsampleArray[rpos / m] = x; // 間引きしてダウンサンプリング後の配列へ
    rpos++;
    if (rpos == sampleNum) rpos = 0; // 最大サンプル数(通常BLOCK_SIZE*m)までで0に戻す
  }
```
間引きしてダウンサンプリング用配列へ書き込みます。あえてアップサンプリングせずダウンサンプリングすることもできます。カットオフ周波数を0に設定してLPFをかけないようにすることも可能ですが、折り返しノイズを防ぐことはできなくなります。<br>
<br>

---

[fx_upsampling.hpp](https://github.com/kanengomibako/Sodium/blob/main/Src/example/fx_upsampling.hpp) のコード内容について説明します。※ このエフェクトはテスト用で、実際に演奏で使う目的のものではありません。

```c++
  virtual void process(float xL[], float xR[])
  {
    setParam();
    float fxL;

    for (uint16_t i = 0; i < BLOCK_SIZE; i++)
    {
      up.process(xL[i], upArray, fxParam[UP] * BLOCK_SIZE); // アップサンプリングした配列作成
    }

    for (uint16_t i = 0; i < fxParam[UP] * BLOCK_SIZE; i++)
    { // アップサンプリングした配列を処理
      float x = param[GAIN] * upArray[i]; // GAIN
      if (x < -0.5f) x = -0.5f; // -0.5～0.5でクリッピング
      if (x >  0.5f) x =  0.5f;
      down.process(x, downArray, fxParam[UP] * BLOCK_SIZE); // ダウンサンプリングした配列作成
    }

    for (uint16_t i = 0; i < BLOCK_SIZE; i++)
    {
      fxL = downArray[i];
      fxL = param[LEVEL] * fxL; // LEVEL

      xL[i] = bypass.process(xL[i], fxL, fxOn);
    }
  }
```
他のエフェクトでは`for`ループ1つで完結していましたが、アップサンプリング後の処理はループを別に分ける必要があります。アップサンプリングした倍率の分処理するサンプル数が増え、より計算負荷がかかることになります。

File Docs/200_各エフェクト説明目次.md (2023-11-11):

# 各エフェクト説明目次

- [音量調整・バイパス](210_音量調整・バイパス.md)
- [1次ローパス・ハイパスフィルタ](220_1次ローパス・ハイパスフィルタ.md)
- [双二次フィルタ](221_双二次フィルタ.md)
- [クリッピング・オーバードライブ](230_クリッピング・オーバードライブ.md)
- [波形変形・ディストーション](231_波形変形・ディストーション.md)
- [アップサンプリング・ダウンサンプリング](233_アップサンプリング・ダウンサンプリング.md)
- [オシレータ・トレモロ](240_オシレータ・トレモロ.md)
- [フェイザー](241_フェイザー.md)
- [ディレイ](250_ディレイ.md)
- [ビブラート・コーラス](251_ビブラート・コーラス.md)
- [オートワウ](260_オートワウ.md)
- [コンプレッサー](261_コンプレッサー.md)

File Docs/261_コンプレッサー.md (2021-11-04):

# コンプレッサー

コンプレッサーは、ギター／ベースの音量が一定値以上になったことを検知して音量を下げる（＝圧縮する）エフェクトです。[オートワウ](260_オートワウ.md)の時と同様に、絶対値とローパスフィルタ（LPF）でエンベロープ値を取得し利用することにします。

圧縮開始の速さがアタック、圧縮を元に戻す速さがリリースというパラメータです。アタック・リリースの調整にも LPF を使うことにしました。この LPF のカットオフ周波数を低くすると、高い周波数が削られる＝値の変化が緩やかになるため、反応を遅くすることができます。

---
[fx_compressor.hpp](https://github.com/kanengomibako/Sodium/blob/main/Src/example/fx_compressor.hpp) のコード内容について説明します。

```c++
private:
  const string name = "COMPRESSOR";
  const uint16_t color = COLOR_RGB; // 白
  const string paramName[20] = {"LEVEL", "THRE", "RATIO", "ATK", "REL", "KNEE"};
  enum paramName {LEVEL, THRESHOLD, RATIO, ATTACK, RELEASE, KNEE};
  float param[20] = {1, 1, 1, 1, 1, 1};
  const int16_t paramMax[20] = {100,  0, 11,100,400, 20};
  const int16_t paramMin[20] = {  0,-90,  2,  4,  5,  0};
  const uint8_t paramNumMax = 6;

  signalSw bypass;
  lpf lpfEnv;    // エンベロープ用ローパスフィルタ
  lpf lpfAtkRel; // アタック・リリース用ローパスフィルタ
```
一般的なパラメータに加えて、効き方を滑らかにする`KNEE`というコントロールがあります（別途最下部で説明）。<br>
<br>

```c++
  virtual void init()
  {
    //（中略）

    lpfEnv.set(500.0f); // エンベロープ用ローパスフィルタ設定
    lpfAtkRel.set(100.0f);
  }
```
アタック・リリースの反応を速くするため、エンベロープ用 LPF はほとんどかけていないくらいのカットオフ周波数となっています。<br>
<br>

```c++
  virtual void setParam()
  {
    //（中略）
    
      case 3:
        param[ATTACK] = 100.0f / (float)fxParam[ATTACK]; // ATTACK 4～100ms(LPF周波数1～25Hz)
        break;
      case 4:
        param[RELEASE] = 400.0f / (float)fxParam[RELEASE]; // RELEASE 5～400ms(LPF周波数1～80Hz)
        break;
      case 5:
        param[KNEE] = (float)fxParam[KNEE]; // KNEE 0～20dB
        break;
      default:
        break;
    }
  }
```
アタック・リリース時間（ミリ秒）はあくまで目安で、厳密な時間設定ではありません。実測して確認すると、アタック・リリース用 LPF のカットオフ周波数と反応の速さは概ね反比例の関係になっているようです。

アタック・リリース時間を短く設定していると、周波数の低い音はどうしても波形のゆがみが大きくなってしまいます。ベースでは特に注意しながら調整する必要がありそうです。<br><br>

```c++
  virtual void process(float xL[], float xR[])
  {
    setParam();

    for (uint16_t i = 0; i < BLOCK_SIZE; i++)
    {
      float fxL = xL[i];
      float th = param[THRESHOLD]; // スレッショルド 一時変数
      float dbGain = 0.0f; // コンプレッション(音量圧縮)幅 dB

      float env = abs(fxL);      // エンベロープ
      env = lpfEnv.process(env); // 絶対値とLPFでエンベロープ取得
      env = gainToDb(env);       // dB換算

      if (env < th - param[KNEE])
      {
        dbGain = 0.0f;
        lpfAtkRel.set(param[RELEASE]);      // リリース用LPF周波数を設定
        dbGain = lpfAtkRel.process(dbGain); // リリース用LPFで音量変化を遅らせる
      }
      else
      {
        if (env < th + param[KNEE]) // THRESHOLD ± KNEE の範囲では2次関数の曲線を使用
        {
          th = -0.25f / param[KNEE] * (env - th - param[KNEE]) * (env - th - param[KNEE]) + th;
        }
        dbGain = (env - th) * param[RATIO] + th - env; // 音量圧縮幅計算
        lpfAtkRel.set(param[ATTACK]);       // アタック用LPF周波数を設定
        dbGain = lpfAtkRel.process(dbGain); // アタック用LPFで音量変化を遅らせる
      }

      fxL = dbToGain(dbGain) * fxL; // コンプレッション実行
      fxL = param[LEVEL] * fxL;     // LEVEL

      xL[i] = bypass.process(xL[i], fxL, fxOn);
    }

  }
```
`RATIO`= ∞ での入力 x と出力 y の関係をグラフにすると下図になります。

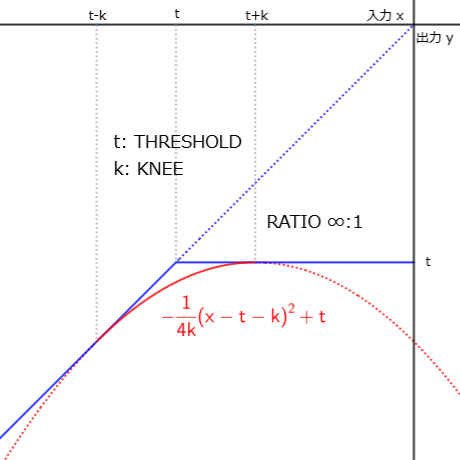
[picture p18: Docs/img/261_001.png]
xy
 

通常は入力が`THRESHOLD`以上で圧縮をかけますが、`KNEE`により`THRESHOLD`付近の圧縮動作を滑らかにします。`THRESHOLD`±`KNEE`の範囲では、2次関数の式を使って`THRESHOLD`を再定義しています。

音量圧縮幅`dbGain`は、出力音から入力音を引いて算出しています。

（例）入力 -20 dB、`THRESHOLD` -30 dB、`RATIO` 5 のとき  
　　出力音：{ (-20) - (-30) } / 5 + (- 30) = -28  
　　出力音 - 入力音：-28 - (-20) = -8 （入力音を -8 dB 変化させる）

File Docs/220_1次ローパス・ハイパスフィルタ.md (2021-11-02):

# 1次ローパス・ハイパスフィルタ

アナログ回路において抵抗器1個とコンデンサ1個で構成されるような1次フィルタについて、デジタルでの実装を説明します。※ デジタルフィルタの原理を理解するのは難しいため、結果のみ利用することにします。

---

1次フィルタは次の式で表されます（a<sub>1</sub> の符号はマイナスで記載されていることがあります）。

- y<sub>n</sub> = b<sub>0</sub> x<sub>n</sub> + b<sub>1</sub> x<sub>n-1</sub> + a<sub>1</sub> y<sub>n-1</sub>　【 x<sub>n</sub>：入力データ　y<sub>n</sub>：出力データ　b<sub>0</sub> 、b<sub>1</sub> 、a<sub>1</sub> ：定数】

x<sub>n-1</sub> や y<sub>n-1</sub> は、1つ前の入出力データです（遅延させたものといわれる場合もあります）。前回のデータを保存しておき、次回計算の時に使用します。

カットオフ周波数 fc により定数が変わり、次の式となります。

- a 【 fs：サンプリング周波数】

- 1次ローパスフィルタ（LPF）

  b<sub>0</sub> = b<sub>1</sub> = (1 - a<sub>1</sub>) / 2

- 1次ハイパスフィルタ（HPF）

  b<sub>0</sub> = - b<sub>1</sub> = (1 + a<sub>1</sub>) / 2

【参考ページ】
- [The Scientist and Engineer's Guide to Digital Signal Processing](http://www.dspguide.com/) - [Chapter 19: Recursive Filters](https://www.dspguide.com/ch19/1.htm)
- [IIR filter design equations for Sound Terminal® devices](https://www.st.com/resource/ja/application_note/dm00038862.pdf) (pdf)

---

[lib_filter.hpp](https://github.com/kanengomibako/Sodium/blob/main/Src/example/lib_filter.hpp) のコード内容について説明します。

- 定数 a<sub>1</sub> の計算

```c++
/* 2 * PI * fc / fs 計算 -----------------------------*/
inline float omega(float fc)
{
  return 2.0f * PI * fc / SAMPLING_FREQ;
}

/* 1次LPF、HPF、APF用の係数計算 tanを近似 誤差10kHz:-1% 14kHz:-2% 17kHz:-3% -------*/
inline float lpfCoef(float fc)
{
  // 近似でない計算式(不使用)
  //float w = PI * fc / SAMPLING_FREQ; // 2 * PI * fc / fs の2分の1を計算
  //return (1 - tanf(w)) / (1 + tanf(w));

  float w = 0.25f * PI * fc / SAMPLING_FREQ; // 2 * PI * fc / fs の8分の1を計算
  float w2 = w * w;
  float w3 = w2 * w;
  float w4 = w2 * w2;
  return (w4 + 4.0f * w3 - 6.0f * w2 - 4.0f * w + 1.0f) /
         (w4 - 4.0f * w3 - 6.0f * w2 + 4.0f * w + 1.0f);
}
```
高速化のため、近似式を使用しています（2倍角の公式を2回使い、tan ω = ω で近似して計算）。高い周波数だとズレがやや大きくなりますが、実用上問題はありません。<br>
<br>

- LPF
```c++
  void set(float fc)
  {
    a1 = lpfCoef(fc);
    b0 = 0.5f * (1.0f - a1);
  }

  float process(float x)
  {
    float y = b0 * x + b0 * x1 + a1 * y1; // b1 = b0
    x1 = x;
    y1 = y;
    return y;
  }
```
- HPF
```c++
  void set(float fc)
  {
    a1 = lpfCoef(fc);
    b0 = 0.5f * (1.0f + a1);
  }

  float process(float x)
  {
    float y = b0 * x - b0 * x1 + a1 * y1; // b1 = -b0
    x1 = x;
    y1 = y;
    return y;
  }
```
`set`関数でカットオフ周波数を設定し、`process`関数でフィルタを実行します。x1、y1に計算結果を保存しておき、次回呼び出し時にそれを利用して計算します。<br>

---

[fx_filter.hpp](https://github.com/kanengomibako/Sodium/blob/main/Src/example/fx_filter.hpp) は、音量調整とLPF・HPFをかけるエフェクトです。コード内容について説明します。

```c++
private:
  const string name = "FILTER";
  const uint16_t color = COLOR_G; // 緑
  const string paramName[20] = {"LV", "LPF", "HPF"};
  enum paramName {LEVEL, LPF, HPF};
  float param[20] = {1, 1, 1};
  const int16_t paramMax[20] = { 20, 99,100};
  const int16_t paramMin[20] = {-20,  1,  1};
  const uint8_t paramNumMax = 3;

  signalSw bypass;
  lpf lpf1;
  hpf hpf1;
```
パラメータ設定はフィルタのカットオフ周波数とゲインです。下部でフィルタのインスタンス生成を行っています。<br>
<br>

```c++
  virtual void setParam()
  {
    static uint8_t count = 0;
    count = (count + 1) % 10; // 負荷軽減のためパラメータ計算を分散させる
    switch(count)
    {
      case 0:
        param[LEVEL] = dbToGain(fxParam[LEVEL]); // LEVEL -20...+20 dB
        break;
      case 1:
        param[LPF] = (float)fxParam[LPF] * 100.0f; // 1次LPF カットオフ周波数 100...9900 Hz
        lpf1.set(param[LPF]);
        break;
      case 2:
        param[HPF] = (float)fxParam[HPF] * 10.0f; // 1次HPF カットオフ周波数 10...1000 Hz
        hpf1.set(param[HPF]);
        break;
      default:
        break;
    }
  }
```
`set`関数でカットオフ周波数設定を更新します。<br>
<br>

```c++
  virtual void process(float xL[], float xR[])
  {
    setParam();

    for (uint16_t i = 0; i < BLOCK_SIZE; i++)
    {
      float fxL = xL[i];
      fxL = lpf1.process(fxL); // 1次LPF
      fxL = hpf1.process(fxL); // 1次HPF
      fxL = param[LEVEL] * fxL; // LEVEL
      xL[i] = bypass.process(xL[i], fxL, fxOn);
    }
  }
```
エフェクト用データ`fxL`に対し、順に`process`関数を実行します。

[lib_filter.hpp](https://github.com/kanengomibako/Sodium/blob/main/Src/example/lib_filter.hpp) には`lpf2nd`と`hpf2nd`という2次フィルタのクラスも準備しています。これは単純に1次フィルタを2回かけたもので、使い方は1次フィルタと同じです。

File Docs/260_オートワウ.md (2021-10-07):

# オートワウ

オートワウはエンベロープフィルタとも呼ばれ、ギター／ベースの音量変化に応じてバンドパスフィルタ（BPF）の中心周波数が変わるエフェクトです。

エンベロープは、音量や音量変化という意味で用いられます。エンベロープ値を取得する方法については下記ページが参考になります。

・[Digital Envelope Detection](https://www.dsprelated.com/showarticle/938.php)

アナログ回路では絶対値とローパスフィルタ（LPF）が使われることが多いので、今回はそれと同様の方法にすることにします。

---
[fx_autowah.hpp](https://github.com/kanengomibako/Sodium/blob/main/Src/example/fx_autowah.hpp) のコード内容について説明します。

```c++
private:
  const string name = "AUTOWAH";
  const uint16_t color = COLOR_G; // 緑
  const string paramName[20] = {"LEVEL", "SENS", "Q", "HiF", "LowF"};
  enum paramName {LEVEL, SENS, Q, HIFREQ, LOFREQ};
  float param[20] = {1, 1, 1, 1, 1};
  const int16_t paramMax[20] = {100,100, 90, 90, 90};
  const int16_t paramMin[20] = {  0,  0, 10, 10, 10};
  const uint8_t paramNumMax = 5;

  signalSw bypass;
  lpf lpf1, lpf2; // エンベロープ用ローパスフィルタ
  biquadFilter bpf1; // ワウ用バンドパスフィルタ
  float logFreqRatio = 0.6f; // バンドパスフィルタ中心周波数計算用変数
```
`Q`値はバンドパスフィルタの鋭さです。`HiF`と`LowF`でワウがかかる周波数の高低を調整できます。

エンベロープ用 LPF は 2 つで、周波数は固定です。1 つでも問題ないかもしれません。`logFreqRatio`は別途最下部で説明します。<br>
<br>

```c++
  virtual void init()
  {
    //（中略）

    lpf1.set(20.0f); // エンベロープ用ローパスフィルタ設定
    lpf2.set(50.0f);
    bpf1.setBPF(1000.0f, 1.0f); // ワウ用バンドパスフィルタ初期値
  }
```
LPF のカットオフ周波数は、低いほどエンベロープの変化曲線が滑らかになります。ただし、低すぎるとアタック／リリース時の反応が遅く感じられるかもしれません。<br>
<br>

```c++
  virtual void process(float xL[], float xR[])
  {
    setParam();

    for (uint16_t i = 0; i < BLOCK_SIZE; i++)
    {
      float fxL = xL[i];

      float env = abs(fxL);
      env = lpf1.process(env); // 絶対値とLPFでエンベロープ取得
      env = gainToDb(env);     // dB換算
      env = env + param[SENS]; // SENSITIVITY 感度(エンベロープ補正)
      if (env > 0.0f) env = 0.0f; // -20～0dBまででクリップ
      if (env < -20.0f) env = -20.0f;

      env = lpf2.process(env); // 急激な変化を避ける

      float freq = param[HIFREQ] * dbToGain(logFreqRatio * env); // エンベロープに応じた周波数を計算 指数的変化
      bpf1.setBPF(freq, param[Q]); // フィルタ周波数を設定

      fxL = bpf1.process(fxL);  // フィルタ(ワウ)実行
      fxL = param[LEVEL] * fxL; // LEVEL

      xL[i] = bypass.process(xL[i], fxL, fxOn);
    }
  }
```
絶対値と LPF でエンベロープを取得し、`SENS`で調整後、エンベロープに応じた BPF の中心周波数を計算します。周波数が異常な値に設定されることを防ぐため、有効なエンベロープ幅を -20 ～ 0 dB に制限しておきます。-20 dB 時に最低周波数`param[LOFREQ]`、0 dB 時に最高周波数`param[HIFREQ]`になります。

- BPF 中心周波数（`freq`）の計算について

  BPF 中心周波数の最高／最低の比率を A（= 20 dB で A 倍の周波数変化）とすると、`param[HIFREQ] * powf(A, env / 20)`という計算をすることになります。計算負荷が軽い`dbToGain`関数を使うために底を 10 に変換すると、`param[HIFREQ] * powf(10, log10f(A) * env / 20)`です。これを`dbToGain`と`logFreqRatio`を使って表したのが`freq`の式となっています。

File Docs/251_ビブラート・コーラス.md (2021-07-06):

# ビブラート・コーラス

前回の[ディレイ](250_ディレイ.md)に引き続き、ディレイタイムを変化させることを考えます。周期的にディレイタイムを変化させると、音程が揺れてビブラートがかかります。ビブラートをかけた音と原音をミックスすると、コーラスとなります。

ディレイバッファ配列に保存している音声信号データは、1 サンプル時間ごとの飛び飛びの値です。ディレイタイムを滑らかに変化させる場合は、サンプルとサンプルの間の値を使う必要が出てきます。そこで、データ読み出し時に線形補間（Lerp: Linear Interpolate）を行うようにします。

[lib_delay.hpp](https://github.com/kanengomibako/Sodium/blob/main/Src/example/lib_delay.hpp) 内のクラス`delayBufF`の`readLerp`関数は以下の内容です。

```c++
  float readLerp(float delayTime) // 線形補間して読み出し コーラス等に利用
  {
    float intervalF = 0.001f * delayTime * SAMPLING_FREQ; // 書込位置と読出位置の間隔を計算 float
    if (intervalF > (float)maxDelaySample) intervalF = (float)maxDelaySample; // 最大ディレイ時間を超えないようにする
    float rposF; // read position 読出位置 float
    if ((float)wpos >= intervalF) rposF = (float)wpos - intervalF; // 読出位置を取得 float
    else rposF = (float)(wpos + maxDelaySample) - intervalF;
    uint32_t rpos0 = (uint32_t)rposF; // 読出位置の前後の整数値を取得
    uint32_t rpos1 = rpos0 + 1;
    if (rpos1 == maxDelaySample) rpos1 = 0; // 読み出し位置最大と0にまたがる場合
    float t = rposF - (float)rpos0; // 線形補間用係数
    return (1 - t) * delayArray[rpos0] + t * delayArray[rpos1]; // 線形補間値を読み出し
  }
```
下図のようなイメージです。

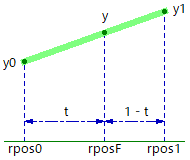
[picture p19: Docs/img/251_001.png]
Array
 

読み出し位置`rposF`を`float`で計算し、前後の整数値`rpos0` `rpos1`を使います。数学的なことについては他のページ（[Wikipedia：線形補間](https://ja.wikipedia.org/wiki/%E7%B7%9A%E5%BD%A2%E8%A3%9C%E9%96%93) 等）をご参照ください。

---
[fx_chorus.hpp](https://github.com/kanengomibako/Sodium/blob/main/Src/example/fx_chorus.hpp) のコード内容について説明します。

```c++
private:
  const string name = "CHORUS";
  const uint16_t color = COLOR_B; // 青
  const string paramName[20] = {"LEVEL", "MIX", "F.BACK", "RATE", "DEPTH", "TONE"};
  enum paramName {LEVEL, MIX, FBACK, RATE, DEPTH, TONE};
  float param[20] = {1, 1, 1, 1, 1, 1};
  const int16_t paramMax[20] = {100,100, 99,100,100,100};
  const int16_t paramMin[20] = {  0,  0,  0,  0,  0,  0};
  const uint8_t paramNumMax = 6;

  signalSw bypass;
  sineWave sin1;
  delayBufF del1;
  hpf hpf1;
  lpf2nd lpf2nd1, lpf2nd2;
```
`MIX`コントロールでビブラート音のみにすることができます。`F.BACK`を上げていくとフランジャーっぽくなります（Resonance や Regeneration というコントロール名の場合があります）。

ディレイタイムを揺らす LFO は正弦波ですが、三角波だと揺れ感が少なくなります。フィルタは二次ローパスフィルタ 2 回分でアナログコーラス風です。<br>
<br>

```c++
  virtual void init()
  {
    //（中略）

    del1.set(20.0f);  // 最大ディレイタイム設定
    hpf1.set(100.0f); // ディレイ音のローカット設定
  }
```
初期化時（起動時またはエフェクト切り替え時）のメモリ確保、ハイパスフィルタ（固定値）の設定を行います。<br>
<br>

```c++
  virtual void deinit()
  {
    del1.erase();
  }
```
終了時（エフェクト切り替え時）にメモリの開放を行います。<br>
<br>

```c++
  virtual void process(float xL[], float xR[])
  {
    setParam();

    for (uint16_t i = 0; i < BLOCK_SIZE; i++)
    {
      float fxL;

      float dtime = 5.0f + param[DEPTH] * (1.0f + sin1.output()); // ディレイタイム 5～15ms
      fxL = del1.readLerp(dtime); // ディレイ音読込(線形補間)
      fxL = lpf2nd1.process(fxL); // ディレイ音のTONE(ハイカット)
      fxL = lpf2nd2.process(fxL);

      // ディレイ音と原音をディレイバッファに書込、原音はローカットして書込
      del1.write(param[FBACK] * fxL + hpf1.process(xL[i]));

      fxL = (1.0f - param[MIX]) * xL[i] + param[MIX] * fxL; // MIX
      fxL = 1.4f * param[LEVEL] * fxL; // LEVEL

      xL[i] = bypass.process(xL[i], fxL, fxOn);
    }
  }
```
正弦波の出力は -1 ～ 1 なので、それを踏まえたディレイタイム設定とします。ディレイタイムの最小値`5.0f`を少なくすると、よりフランジャー向けになります。

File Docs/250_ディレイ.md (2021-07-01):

# ディレイ

音を遅延させるディレイは、RAM 等の保存領域に音声信号データを保存しておき、必要に応じてそのデータを取り出すことで実現できます。

---

モノラル、サンプリング周波数 44.1 kHzの場合、1 秒間に 44100 個のデータがあるので、1 秒の遅延にはこの個数分格納できる配列が必要です。データを 32 bit float 型とすると、容量としては 32 × 44100 = 1411200 ビット（単位換算後 176.4 キロバイト）となります。

下図のように、配列にデータ書き込み→配列の添字を1つ増やす（右に移動）を繰り返します。配列の最後まで到達すると配列の先頭に戻って書き込みます。

Array 

0.5 秒前のデータは、22050 サンプル離れたところにあるため、そこからデータを読み出せば 0.5 秒分遅延した音が取り出せます。一番古いデータは現在書き込む位置の右隣に位置することになります。

※ ディレイバッファ配列は、最後尾と先頭が繋がった円状の配列（リングバッファ）として解説されている場合もあります。

---

[lib_delay.hpp](https://github.com/kanengomibako/Sodium/blob/main/Src/example/lib_delay.hpp) 内のクラス`delayBuf`のコード内容について説明します。

```c++
  void set(float maxDelayTime) // バッファ配列メモリ確保 最大ディレイ時間 ms
  { // ※メモリ確保失敗検知未実装 std::bad_alloc を使う場合は -fexceptions コンパイルオプションが必要
    maxDelaySample = 1 + (uint32_t)(SAMPLING_FREQ * maxDelayTime / 1000.0f); // 最大サンプル数計算
    delayArray = new int16_t[maxDelaySample](); // メモリ確保（0初期化）
  }
```
ディレイバッファ配列用のメモリを動的に確保するため`new`を使います。データ型を`int16_t`にすると保存容量が float の半分で済むため、より長いディレイタイムが可能となります（クラス`delayBufF`が float バージョンです）。何らかの理由でメモリ確保に失敗した場合の処理は現状未実装です。<br>
<br>

```c++
  void erase() // バッファ配列メモリ削除
  {
    delete[] delayArray;
  }
```
`new`で確保したメモリを`delete[]`で開放します。<br>
<br>

```c++
  void write(float x) // バッファ配列書き込み、書込位置を進める
  {
    if (x < -1.00f) x = -1.00f; // オーバーフロー防止
    if (x > 0.999f) x = 0.999f;
    delayArray[wpos] = (int16_t)(x * 32768.0f); // 16ビット整数で書き込み
    wpos++; // 書込位置を1つ進める
    if (wpos == maxDelaySample) wpos = 0; // 最大サンプル数までで0に戻す
  }
```
配列に書き込むと同時に書き込み位置を進める操作も行っています。データ型を`int16_t`にしているため、オーバーフロー防止措置が必要です。<br>
<br>

```c++
  float read(float delayTime) // 通常のサンプル単位での読み出し ディレイ時間 ms
  {
    uint32_t interval = (uint32_t)(0.001f * delayTime * SAMPLING_FREQ); // 書込位置と読出位置の間隔を計算
    if (interval > maxDelaySample) interval = maxDelaySample; // 最大ディレイ時間を超えないようにする
    uint32_t rpos; // read position 読出位置
    if (wpos >= interval) rpos = wpos - interval; // 読出位置を取得
    else rpos = wpos + maxDelaySample - interval;
    return (float)delayArray[rpos] / 32768.0f; // バッファ配列からfloat(-1～1)で読み出し
  }
```
ディレイタイム分のサンプル数（`interval`）を計算し、書き込み位置からその分遡って読み出し位置を割り出します。※ `readLerp`関数については別記事にて説明する予定です。<br>
<br>

---
[fx_delay.hpp](https://github.com/kanengomibako/Sodium/blob/main/Src/example/fx_delay.hpp) のコード内容について説明します。

```c++
private:
  const string name = "DELAY";
  const uint16_t color = COLOR_RB; // 赤青
  const string paramName[20] = {"TIM", "E.LV", "F.BACK", "TONE", "TRAIL", "DIV"};
  enum paramName {DTIME, ELEVEL, FBACK, TONE, TRAIL, TAPDIV};
  float param[20] = {1, 1, 1, 1, 1, 1};
  const int16_t paramMax[20] = {1500,100, 99,100,  1,  5};
  const int16_t paramMin[20] = {  10,  0,  0,  0,  0,  0};
  const uint8_t paramNumMax = 6;

  // 最大ディレイタイム 16bit モノラルで2.5秒程度まで
  const float maxDelayTime = 1500.0f;

  // タップテンポ DIV定数 0←→5で循環させ、実際使うのは1～4
  const string tapDivStr[6]  = {"1/1", "1/1", "1/2", "1/3", "3/4", "1/1"};
  const float tapDivFloat[6] = {1.0f, 1.0f, 0.5f, 0.333333f, 0.75f, 1.0f};

  signalSw bypassIn, bypassOut;
  delayBuf del1;
  lpf2nd lpf2ndTone;
```
ディレイ音を残す`TRAIL`機能、タップテンポ機能を盛り込んでいます。`DIV`はタップテンポで設定した時間を必要に応じて割るためのものです。

バイパスはディレイ音が残らないように入力側と出力側の二つで行います。<br>
<br>

```c++
  virtual void init()
  {
    //（中略）

    del1.set(maxDelayTime); // 最大ディレイタイム分のメモリ確保
  }
```
初期化時（起動時またはエフェクト切り替え時）にメモリ確保を行います。<br>
<br>

```c++
  virtual void deinit()
  {
    del1.erase();
  }
```
終了時（エフェクト切り替え時）にメモリの開放を行います。<br>
<br>

```c++
  virtual void setParam()
  {
    float divTapTime = tapTime * tapDivFloat[fxParam[TAPDIV]]; // DIV計算済タップ時間
    static uint8_t count = 0;
    count = (count + 1) % 10; // 負荷軽減のためパラメータ計算を分散させる
    switch(count)
    {
      case 0:
        if (divTapTime > 10.0f && divTapTime < maxDelayTime) // タップテンポ設定時
        {
          fxParam[DTIME] = (int16_t)divTapTime;
        }
        param[DTIME] = (float)fxParam[DTIME]; // DELAYTIME 10 ～ 1500 ms
        break;
      //（中略）
    }
  }
```
グローバル変数`tapTime`にタップテンポ機能で取得した時間が格納されています（未取得の場合は 0 を格納）。これを実際のディレイタイムに反映させます。<br>
<br>

```c++
  virtual void process(float xL[], float xR[])
  {
    setParam();

    for (uint16_t i = 0; i < BLOCK_SIZE; i++)
    {
      float fxL;

      fxL = del1.read(param[DTIME]); // ディレイ音読込
      fxL = lpf2ndTone.process(fxL); // ディレイ音のTONE（ハイカット）

      // ディレイ音と原音をディレイバッファに書込、原音はエフェクトオン時のみ書込
      del1.write(param[FBACK] * fxL + bypassIn.process(0.0f, xL[i], fxOn));

      fxL = param[ELEVEL] * fxL; // ディレイ音レベル

      xL[i] = xL[i] + bypassOut.process(param[TRAIL] * fxL, fxL, fxOn); // TRAIL ON時ディレイ音残す
    }
  }
```
`fxL`はディレイ音のみ格納しています。ディレイバッファ配列にフィードバックさせたディレイ音を書き込むため、先にディレイ音を読み込んでいます。

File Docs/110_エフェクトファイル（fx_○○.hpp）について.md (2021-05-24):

# エフェクトファイル（fx_○○.hpp）について

[fx_volume.hpp](https://github.com/kanengomibako/Sodium/blob/main/Src/example/fx_volume.hpp) を例に、エフェクトファイル（fx_○○.hpp）のコード内容について説明します。

---

```c++
#include "common.h"

// ライブラリ読込
#include "lib_calc.hpp"
```
[common.h](https://github.com/kanengomibako/Sodium/blob/main/Src/example/common.h)（共通ヘッダ）には全ファイルで共有する事項（グローバル変数等）を記載しています。lib_○○.hpp はある程度まとまった機能を集めたライブラリ的なヘッダファイルです。例えば [lib_calc.hpp](https://github.com/kanengomibako/Sodium/blob/main/Src/example/lib_calc.hpp) にはデシベル計算の関数やエフェクトバイパス処理のクラス等が入っています。フィルタを使うエフェクトの場合は [lib_filter.hpp](https://github.com/kanengomibako/Sodium/blob/main/Src/example/lib_filter.hpp) を読み込む等、必要に応じたヘッダを読み込みます。<br>
<br>
```c++
class fx_volume : public fx_base
```
`fx_volume`の部分にエフェクトのクラス名を記載します。<br>
<br>
```c++
  // 基本設定
  const string name = "VOLUME";       // エフェクト名
  const uint16_t color = COLOR_R;     // エフェクトON時のLED色
  const string paramName[20] = {"G"}; // パラメータ名
  enum paramName {GAIN};              // パラメータ名（配列の添字 識別用）
  float param[20] = {1}; // 信号処理に使うfloatパラメータ(基本編集しない)
  const int16_t paramMax[20] = {20};  // パラメータ設定最大値
  const int16_t paramMin[20] = {-20}; // パラメータ設定最小値
  const uint8_t paramNumMax = 1;      // パラメータ数
```
エフェクトの基本情報を設定します。LED色の定義は [common.h](https://github.com/kanengomibako/Sodium/blob/main/Src/example/common.h) の下部に記載しているので、それを使って色指定するのが簡単です。`enum paramName`の内容は`param[GAIN]`のように配列の添字に使用するので、`string paramName`と同じ内容にしておくとよいです。パラメータ範囲は最小0・最大100とする場合が多いですが、この例ではパラメータ`GAIN`の範囲を -20 dB ～ +20 dB としています。<br>
<br>
```c++
  // インスタンス生成 フィルタ等
  signalSw bypass;
```
バイパス、フィルタ、ディレイ等のクラスのインスタンス生成を行います。<br>
<br>
```c++
  virtual void init() // 初期化処理
  {
    // 現在のエフェクト用の変数に呼び出したエフェクトの設定を読み込ませる
    fxName = name;
    fxColor = color;
    fxParamNumMax = paramNumMax;
    for (int i = 0; i < 20; i++)
    {
      fxParamName[i] = paramName[i];
      fxParamMax[i] = paramMax[i];
      fxParamMin[i] = paramMin[i];

      // 読み込んだデータが範囲外数値の時、最小値へ変更
      if (fxAllData[fxNum][i] < paramMin[i] || fxAllData[fxNum][i] > paramMax[i]) fxParam[i] = paramMin[i];
      else fxParam[i] = fxAllData[fxNum][i];
    }

    // ディレイタイム分のメモリ確保やフィルタ周波数の固定値等をここで設定

  }
```
エフェクト呼び出し時の初期化処理です。まず設定読み込みがありますが、ここは特に編集する必要はありません。ディレイやフィルタ等のクラスを使っている場合は、そのクラスの初期化処理を行います。<br>
<br>
```c++
  virtual void deinit() // 終了処理
  {
  }
```
エフェクトの終了時の処理です。ディレイ等、大きい配列のメモリを確保している場合は、ここで解放します。[user_main.cpp](https://github.com/kanengomibako/Sodium/blob/main/Src/example/user_main.cpp) の fxChange 関数に記載している通り、エフェクト切り替え時は旧エフェクトの`deinit`関数の後に新エフェクトの`init`関数が実行されます。<br>
<br>
```c++
  virtual void setParamStr(uint8_t paramNum) // パラメータ数値を文字列へ変換
  {
    switch(paramNum)
    {
      case 0: // GAINを±●dBで表記
        fxParamStr[GAIN] = std::to_string(fxParam[GAIN]) + "dB";
        if (fxParam[GAIN] > 0) fxParamStr[GAIN] = "+" + fxParamStr[GAIN];
        break;
        //（中略）
        fxParamStr[paramNum] = ""; // 使っていないパラメータの場合は空白にする
        break;
    }
  }
```
[user_main.cpp](https://github.com/kanengomibako/Sodium/blob/main/Src/example/user_main.cpp) のメインループから呼び出され、ディスプレイ表示のためにパラメータ数値を文字列型（string）へ変換します。この例のように「+」「dB」等の追加文字を入れることもできます。<br>
<br>
```c++
  virtual void setParam() // パラメータ数値を実際の信号処理に使うfloat数値へ変換
  {
    static uint8_t count = 0;
    count = (count + 1) % 10; // 負荷軽減のためパラメータ計算を分散させる
    switch(count)
    {
      case 0:
        param[GAIN] = dbToGain(fxParam[GAIN]); // GAIN -20...+20 dB
        break;
        //（中略）
      default:
        break;
    }
  }
```
下記`process`関数から呼び出され、パラメータ数値の float 型への変換、フィルタの周波数を変更する処理等を行います。ブロックサイズごとに実行されますが、さらなる計算負荷軽減のため、1回の呼び出しにつき1個だけパラメータを処理するようにしています。<br>
<br>
```c++
  virtual void process(float xL[], float xR[]) // エフェクト処理
  {
    setParam(); // パラメータ数値計算

    for (uint16_t i = 0; i < BLOCK_SIZE; i++)
    {
      float fxL = xL[i]; // エフェクト処理を行う方の一時変数

      fxL = param[GAIN] * fxL; // ゲイン調整

      xL[i] = bypass.process(xL[i], fxL, fxOn); // バイパス
    }
  }
```
I2S割り込み（[user_main.cpp](https://github.com/kanengomibako/Sodium/blob/main/Src/example/user_main.cpp) の  mainProcess 関数）から呼び出されます。配列`xL`はADCで読み取った入力信号データ（原音）です。別の変数`fxL`を準備し、そちらにエフェクト処理を行っていきます。I2S割り込みはブロックサイズごとに起こるので、`setParam`関数もブロックサイズごとに実行されます。for ループ内で実際の信号処理を記述します。

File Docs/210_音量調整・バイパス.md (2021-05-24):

# 音量調整・バイパス

音量を調整する場合は、掛け算を行います。[fx_volume.hpp](https://github.com/kanengomibako/Sodium/blob/main/Src/example/fx_volume.hpp) での処理は以下の通りです。

```c++
    for (uint16_t i = 0; i < BLOCK_SIZE; i++)
    {
      float fxL = xL[i]; // エフェクト処理を行う方の一時変数

      fxL = param[GAIN] * fxL; // ゲイン調整

      xL[i] = bypass.process(xL[i], fxL, fxOn); // バイパス
    }
```
当然ながら`param[GAIN]`が 2 であれば 2 倍（+6dB）になります。<br>
**※ 音量を上げ過ぎると出力時にクリップし歪んでしまいます。Sodium は最大出力電圧が大きくないので、ブースターとしては利用できません。入力音と出力音は同じぐらいの音量で運用してください。**<br>
<br>
`param[GAIN]`は`setParam`関数内で下記のように計算しています。
```c++
        param[GAIN] = dbToGain(fxParam[GAIN]); // GAIN -20...+20 dB
```
聴覚に合わせた音量調節をする場合、指数関数的にコントロールします（ボリュームポットにAカーブを使うような感覚）。[lib_calc.hpp](https://github.com/kanengomibako/Sodium/blob/main/Src/example/lib_calc.hpp) の`dbToGain`関数で dB から電圧比への変換を行います。（STM32CubeIDEでは、Ctrl+クリックで該当箇所にジャンプできます。）
```c++
inline float dbToGain(float x) // 使用範囲±128dB 最大誤差0.015dB
{
  return dbToGainTable[(uint8_t)(x + 128.0f)]
         + (dbToGainTable[(uint8_t)(x + 128.0f) + 1] - dbToGainTable[(uint8_t)(x + 128.0f)])
           * ((x + 128.0f) - (float)((uint8_t)(x + 128.0f)));
}
```
本来は powf 関数を使った計算式を使いますが、そうすると計算負荷が重すぎます。そこで高速化のため、`dbToGainTable`というテーブルの参照と線形補間を行っています。使用範囲 ±128dB を超えるとオーバーフローしてしまうので注意が必要です。<br>
例）3.5 dB の値（1.496）が必要な時、近似値として 3 dB（1.413）と 4 dB（1.585）の間の値（1.499）を使う<br>
<br>

---

エフェクト音と原音の切り替え（いわゆるエフェクトバイパス）等、信号経路を切り替える際に「プチッ」というノイズが入る場合があります。そこで徐々に音量を変更してから切替できるよう、[lib_calc.hpp](https://github.com/kanengomibako/Sodium/blob/main/Src/example/lib_calc.hpp) にクラス`signalSw`を準備しています。複数の信号経路切替がある場合は、複数のインスタンス生成をすれば問題ありません。

```c++
/* ポップノイズ対策のため、0.01ずつ音量変更しスイッチ操作する（エフェクトバイパス等）--------------*/
class signalSw
{
public:
  float process(float x, float fx, bool sw)
  {
    static uint8_t count = 0;

    if (sw) // エフェクトON
    {
      if (count < 100) // バイパス音量ダウン
      {
        count++;
        return (1.0f - (float)count * 0.01f) * x; // (count: 1～100)
      }
      else if (count < 200) // エフェクト音量アップ
      {
        count++;
        return ((float)count * 0.01f - 1.0f) * fx; // (count: 101～200)
      }
      else // count終了 (count: 200)
      {
        return fx;
      }
    }
    else // エフェクトOFF
    {
      if (count > 100) // エフェクト音量ダウン
      {
        count--;
        return ((float)count * 0.01f - 1.0f) * fx; // (count: 199～100)
      }
      else if (count > 0) // バイパス音量アップ
      {
        count--;
        return (1.0f - (float)count * 0.01f) * x; // (count: 99～0)
      }
      else // count終了 (count: 0)
      {
        return x;
      }
    }
  }

};
```
エフェクトオン時は、原音`x`の音量を徐々に下げる→エフェクト音`fx`の音量を徐々に上げるという流れで、エフェクトオフ時は逆になります。切替には 200 カウント分にあたる 4.5 ms （サンプリング周波数 44100 Hz 時）の時間がかかります。

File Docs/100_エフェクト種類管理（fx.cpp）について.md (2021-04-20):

# エフェクト種類管理（ fx.cpp ）について

エフェクトの種類や切替を管理しているファイル [fx.cpp](https://github.com/kanengomibako/Sodium/blob/main/Src/example/fx.cpp) のコード内容について説明します。C++の継承（基底クラス、派生クラス、抽象クラス等）の解説については他のサイトをご参照ください。

---

```c++
// 基底クラス ヘッダー
#include "fx_base.hpp"

// 各エフェクト 派生クラス ヘッダー
#include "fx_volume.hpp"
//（以下略）
```
基底クラスと各エフェクトのヘッダファイルを読み込みます。使わないエフェクトに関する記述は消さずに残しておいて問題ありません。エフェクトのヘッダファイルには「fx_」という接頭辞をつけています。<br>
<br>
```c++
// 各エフェクト グローバルインスタンス生成
fx_volume vo1;
//（以下略）
```
各エフェクトの実体を生成します。`fx_volume`が [fx_volume.hpp](https://github.com/kanengomibako/Sodium/blob/main/Src/example/fx_volume.hpp) 内に記載しているクラス名です。`vo1`にあたる部分はどんな名前でもよいですが、次の項目でも使うのでわかりやすいようにします。`vo1, vo2`という風に複数のインスタンス生成も可能です。<br>
<br>
```c++
// 各エフェクト用ポインタ配列を生成(&を付ける)
// 使用するエフェクトを記載、順番入れ替え可
fx_base* effect[] = {&vo1, &od1, &dd1, &tr1, &ce1, &ph1, &rv1};
```
基底クラスのポインタ配列を作り、それに各エフェクトのポインタを割り当てます。先ほど生成したインスタンス`vo1`等のうち、使用するものに&を付け記載します。エフェクト切替順は記載した順番となります。

例：`fx_base* effect[] = {&dd1, &od1, &rv1, &ce1};`

※ エフェクトを入れ替えた場合、保存していたパラメータ数値は引き継がれません。<br>
<br>
```c++
const uint8_t fxNumMax = sizeof(effect) / sizeof(effect[0]); // エフェクト最大数を自動計算

uint32_t cpuUsageCycleMax[fxNumMax] = {}; // CPU使用サイクル数 各エフェクトごとに最大値を記録
int16_t fxAllData[fxNumMax][20] = {}; // 全てのエフェクトパラメータデータ配列
```
使用エフェクト数`fxNumMax`を計算し、それが入ったグローバル変数を定義しています。<br>
<br>
```c++
// エフェクト処理
void fxProcess(float xL[], float xR[])
{
  effect[fxNum]->process(xL, xR);
}

// 初期化処理 パラメータ読込、ディレイ用メモリ確保等
void fxInit()
{
  effect[fxNum]->init();
}

// 終了処理 ディレイ用メモリ削除等
void fxDeinit()
{
  effect[fxNum]->deinit();
}

// エフェクトパラメータ文字列更新処理
void fxSetParamStr(uint8_t paramNum)
{
  effect[fxNum]->setParamStr(paramNum);
}
```
各エフェクトの関数を実行します。配列`effect[fxNum]`には各エフェクトが割り当てられているため、`fxNum`が変わると実行されるエフェクト処理が切り替わるという仕組みとなっています。各関数の詳細については[エフェクトファイル解説](110_エフェクトファイル（fx_○○.hpp）について.md)にて説明します。

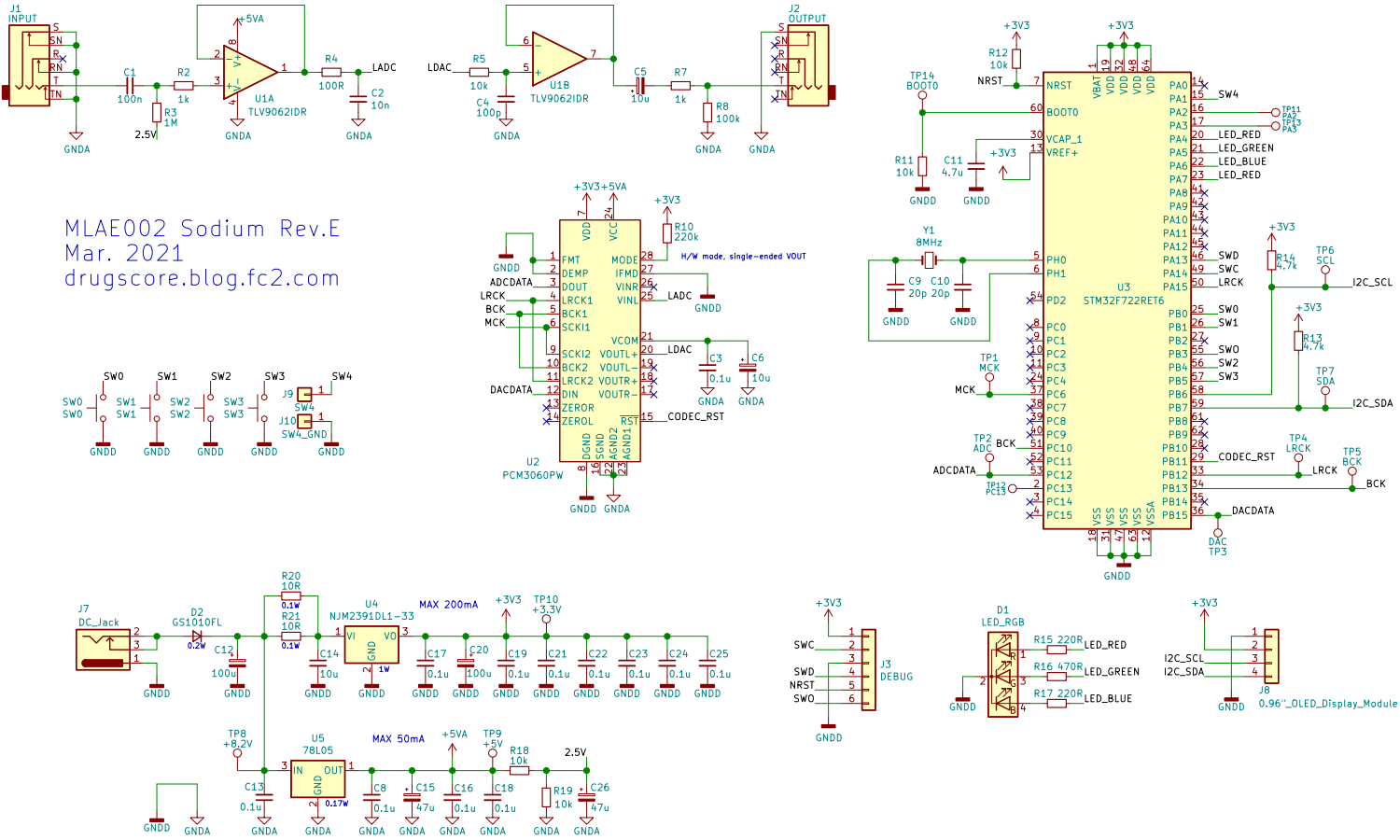
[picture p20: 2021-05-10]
Sodium_sch.png

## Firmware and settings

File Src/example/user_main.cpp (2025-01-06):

#include "common.h"
#include "user_main.h"
#include "main.h"
#include "ssd1306.hpp"
#include "fx.hpp"

#if TUNER_ENABLED
#include "tuner.hpp"
#endif

extern I2C_HandleTypeDef hi2c1;
extern I2S_HandleTypeDef hi2s2;
extern I2S_HandleTypeDef hi2s3;

#define __ATTR_DTCMRAM  __attribute__ ((section(".DTCMRAM"))) __attribute__ ((aligned (4)))
int32_t RxBuffer[BLOCK_SIZE*4] __ATTR_DTCMRAM; // 音声信号受信バッファ配列 Lch前半 Lch後半 Rch前半 Rch後半
int32_t TxBuffer[BLOCK_SIZE*4] __ATTR_DTCMRAM; // 音声信号送信バッファ配列

uint32_t callbackCount = 0; // I2Sの割り込みごとにカウントアップ タイマとして利用
extern uint32_t cpuUsageCycleMax[]; // CPU使用サイクル数
const float i2sInterruptInterval = (float)BLOCK_SIZE / SAMPLING_FREQ; // I2Sの割り込み間隔時間

// スイッチ短押し、スイッチ長押し、ステータス情報表示時間のカウント数
const uint32_t shortPushCount = 1 + SHORT_PUSH_MSEC / (4 * 1000 * i2sInterruptInterval); // 1つのスイッチは4回に1回の読取のため4をかける
const uint32_t longPushCount = 1 + LONG_PUSH_MSEC / (4 * 1000 * i2sInterruptInterval);
const uint32_t statusDispCount = 1 + STATUS_DISP_MSEC / (1000 * i2sInterruptInterval);

bool fxOn = false; // エフェクトオン・オフ状態
string fxName = ""; // 現在のエフェクト名
uint16_t fxColor = 0; // 現在のエフェクトLED色 RGB565
string fxParamName[20] = {}; // エフェクトパラメータ名 LEVEL, GAIN等
int16_t fxParam[20] = {}; // 現在のエフェクトパラメータ数値
string fxParamStr[20] = {}; // 現在のエフェクトパラメータ数値 文字列
int16_t fxParamMax[20] = {}; // エフェクトパラメータ最大値
int16_t fxParamMin[20] = {}; // エフェクトパラメータ最小値

uint8_t fxParamNum = 0; // エフェクトパラメータ 現在何番目か ※0から始まる
uint8_t fxParamNumMax = 0; // エフェクトパラメータ数 最大値

uint8_t fxNum = 0; // 現在のエフェクト番号 ※0から始まる
int8_t fxChangeFlag = 0; // エフェクト種類変更フラグ 次エフェクトへ: 1 前エフェクトへ: -1

uint8_t cursorPosition = 0; // パラメータ選択カーソル位置 0 ～ 5
string statusStr = PEDAL_NAME; // ステータス表示文字列

enum modeName {NORMAL, TAP, TUNER};
uint8_t mode = NORMAL; // 動作モード 0:通常 1:タップテンポ 2:チューナー

float tapTime = 0.0f; // タップテンポ入力時間 ms

const uint8_t fxNameXY[2] = {4,0}; // エフェクト名 ステータス 表示位置
const uint8_t fxPageXY[2] = {88,0}; // エフェクトパラメータ ページ 表示位置
const uint8_t percentXY[2] = {107,0}; // 処理時間% 表示位置
const uint8_t cursorPositionXY[6][2] = {{0,11},{0,29},{0,47},{65,11},{65,29},{65,47}}; // カーソル位置
const uint8_t fxParamNameXY[6][2] = {{0,17},{0,35},{0,53},{65,17},{65,35},{65,53}}; // エフェクトパラメータ名表示位置
const uint8_t fxParamStrXY[6][2]  = {{52,11},{52,29},{52,47},{117,11},{117,29},{117,47}}; // エフェクトパラメータ数値表示 右端の文字位置

void mainInit() // <<<<<<<<<<<<<<<<<<<<<<<<<<<<<<<<<<<<<<<<<<<最初に1回のみ行う処理
{
  // Denormalized numbers（非正規化数）を0として扱うためFPSCRレジスタ変更
  asm("VMRS r0, FPSCR");
  asm("ORR r0, r0, #(1 << 24)");
  asm("VMSR FPSCR, r0");

  // 処理時間計測用設定
  CoreDebug->DEMCR |= CoreDebug_DEMCR_TRCENA_Msk;
  DWT->CTRL |= DWT_CTRL_CYCCNTENA_Msk;

  // ディスプレイ初期化
  ssd1306_Init(&hi2c1);

#if 0
  // ディスプレイ点灯確認
  ssd1306_Fill(White);
  ssd1306_SetCursor(3, 22);
  ssd1306_WriteString(PEDAL_NAME, Font_11x18, Black);
  ssd1306_UpdateScreen(&hi2c1);

  // LED点灯確認
  HAL_GPIO_WritePin(LED_RED_GPIO_Port, LED_RED_Pin, GPIO_PIN_SET);
  HAL_Delay(300);
  HAL_GPIO_WritePin(LED_RED_GPIO_Port, LED_RED_Pin, GPIO_PIN_RESET);
  HAL_GPIO_WritePin(LED_GREEN_GPIO_Port, LED_GREEN_Pin, GPIO_PIN_SET);
  HAL_Delay(300);
  HAL_GPIO_WritePin(LED_GREEN_GPIO_Port, LED_GREEN_Pin, GPIO_PIN_RESET);
  HAL_GPIO_WritePin(LED_BLUE_GPIO_Port, LED_BLUE_Pin, GPIO_PIN_SET);
  HAL_Delay(300);
  HAL_GPIO_WritePin(LED_BLUE_GPIO_Port, LED_BLUE_Pin, GPIO_PIN_RESET);
#endif

  // 起動時フットスイッチ、左上スイッチ、右下スイッチを押していた場合、データ全消去
  if (!HAL_GPIO_ReadPin(SW0_UPPER_L_GPIO_Port, SW0_UPPER_L_Pin) &&
      !HAL_GPIO_ReadPin(SW3_LOWER_R_GPIO_Port, SW3_LOWER_R_Pin) &&
      !HAL_GPIO_ReadPin(SW4_FOOT_GPIO_Port, SW4_FOOT_Pin))
  {
    ssd1306_SetCursor(0, 0);
    ssd1306_WriteString("ERASE ALL DATA", Font_7x10, Black);
    ssd1306_UpdateScreen(&hi2c1);
    eraseData();
    HAL_Delay(1000);
  }

  // 保存済パラメータ読込 エフェクト番号(fxNum)読込
  loadData();

  // 初期エフェクト読込 ※信号処理が始まる前にメモリ確保
  fxInit();

  // I2SのDMA開始
  HAL_I2S_Transmit_DMA(&hi2s2, (uint16_t*)TxBuffer, BLOCK_SIZE*4);
  HAL_I2S_Receive_DMA(&hi2s3, (uint16_t*)RxBuffer, BLOCK_SIZE*4);

  // オーディオコーデック リセット
  HAL_GPIO_WritePin(CODEC_RST_GPIO_Port, CODEC_RST_Pin, GPIO_PIN_RESET);
  HAL_Delay(100);
  HAL_GPIO_WritePin(CODEC_RST_GPIO_Port, CODEC_RST_Pin, GPIO_PIN_SET);
  HAL_Delay(100);

  // I2Sのフレームエラー発生の場合、リセットを繰り返す
  while(__HAL_I2S_GET_FLAG(&hi2s2, I2S_FLAG_FRE) || __HAL_I2S_GET_FLAG(&hi2s3, I2S_FLAG_FRE))
  {
    ssd1306_SetCursor(0, 0);
    ssd1306_WriteString("ERROR",Font_11x18,Black);
    ssd1306_UpdateScreen(&hi2c1);
    HAL_GPIO_WritePin(CODEC_RST_GPIO_Port, CODEC_RST_Pin, GPIO_PIN_RESET);
    HAL_Delay(100);
    HAL_GPIO_WritePin(CODEC_RST_GPIO_Port, CODEC_RST_Pin, GPIO_PIN_SET);
    HAL_Delay(100);
  }

}

void mainLoop() // <<<<<<<<<<<<<<<<<<<<<<<<<<<<<<<<<<<<<<<<<<<メインループ
{
  ssd1306_Fill(Black); // 一旦画面表示を全て消す

  if (mode == NORMAL) // 通常モード *****************************
  {
    uint8_t fxPage = fxParamNum / 6; // エフェクトパラメータページ番号

    // ステータス表示 デフォルト表示はfxName ------------------------------
    static bool statusChangeStart = false; // ステータス表示変更開始フラグ
    static string tmpStatus = ""; // ステータス表示点滅用一時変数

    if (statusStr != fxName) // エフェクト名以外のステータス表示
    {
      if (!statusChangeStart) // ステータス表示変更開始処理
      {
        callbackCount = 0;
        statusChangeStart = true;
        tmpStatus = statusStr;
      }

      if (callbackCount > statusDispCount) // 一定時間経過後、デフォルト表示に戻す
      {
        statusStr = fxName;
        statusChangeStart = false;
      }
      else if ((callbackCount / (statusDispCount/6)) % 2 == 0) statusStr = tmpStatus; // 一定時間経過まで点滅
      else statusStr = "";
    }
    ssd1306_xyWriteStrWT(fxNameXY[0], fxNameXY[1], statusStr, Font_7x10);

    // エフェクトパラメータ名称表示------------------------------
    for (int i = 0; i < 6; i++)
    {
      ssd1306_xyWriteStrWT(fxParamNameXY[i][0], fxParamNameXY[i][1], fxParamName[i+3*fxPage], Font_7x10);
    }

    // エフェクトパラメータ数値表示------------------------------
    for (int i = 0; i < 6; i++)
    {
      fxSetParamStr(i+6*fxPage); // パラメータ数値を文字列に変換
      ssd1306_R_xyWriteStrWT(fxParamStrXY[i][0], fxParamStrXY[i][1], fxParamStr[i+3*fxPage], Font_11x18);
    }

    // エフェクトパラメータページ番号表示------------------------------
    string fxPageStr = "P" + std::to_string(fxPage + 1);
    ssd1306_xyWriteStrWT(fxPageXY[0], fxPageXY[1], fxPageStr, Font_7x10);

    // カーソル表示(選択したパラメータの白黒反転) ------------------------------
    for (int i = 0; i < 62; i++)
    {
      for (int j = 0; j < 16; j++)
      {
        ssd1306_InvertPixel(cursorPositionXY[cursorPosition][0]+i, cursorPositionXY[cursorPosition][1]+j);
      }
    }

    // CPU使用率表示------------------------------
    uint8_t cpuUsagePercent = 100.0f * cpuUsageCycleMax[fxNum] / SystemCoreClock / i2sInterruptInterval;
    string percentStr = std::to_string(cpuUsagePercent);
    if (cpuUsagePercent < 10) percentStr = " " + percentStr + "%"; // 右揃えにする
    else percentStr = percentStr + "%";
    ssd1306_xyWriteStrWT(percentXY[0], percentXY[1], percentStr, Font_7x10);

  }

  if (mode == TAP) // タップテンポモード *****************************
  {
    ssd1306_xyWriteStrWT(0, 0, "TAP TEMPO", Font_7x10);
    string tmpStr = std::to_string((uint16_t)tapTime);
    ssd1306_R_xyWriteStrWT(114, 0, tmpStr + " ms", Font_7x10); // タップ間隔時間を表示
    if (tapTime > 60.0f) tmpStr = std::to_string((uint16_t)(60000.0f / tapTime)); // bpmを計算
    ssd1306_R_xyWriteStrWT(103, 20, tmpStr + " bpm", Font_16x26); // bpm表示

    uint16_t blinkCount = 1 + tapTime / (1000 * i2sInterruptInterval); // 点滅用カウント数
    if (callbackCount % blinkCount < 60 / (1000 * i2sInterruptInterval)) // 60msバーを表示、点滅
    {
      for (int i = 0; i < 112; i++)
      {
        ssd1306_DrawPixel(8 + i, 47, White);
        ssd1306_DrawPixel(8 + i, 48, White);
      }
    }
  }

  if (mode == TUNER) // チューナーモード *****************************
  {
#if TUNER_ENABLED
    tunerDisp();
#endif
  }

  // 画面更新------------------------------
  ssd1306_UpdateScreen(&hi2c1);
  //HAL_Delay(10);

  // LED表示------------------------------
  uint8_t r = (fxColor >> 8) & 0b0000000011111000; // RGB565を変換 PWMで色を制御する場合使えるかも
  uint8_t g = (fxColor >> 3) & 0b0000000011111100;
  uint8_t b = (fxColor << 3) & 0b0000000011111000;
  if (r && fxOn) HAL_GPIO_WritePin(LED_RED_GPIO_Port, LED_RED_Pin, GPIO_PIN_SET);
  else HAL_GPIO_WritePin(LED_RED_GPIO_Port, LED_RED_Pin, GPIO_PIN_RESET);
  if (g && fxOn) HAL_GPIO_WritePin(LED_GREEN_GPIO_Port, LED_GREEN_Pin, GPIO_PIN_SET);
  else HAL_GPIO_WritePin(LED_GREEN_GPIO_Port, LED_GREEN_Pin, GPIO_PIN_RESET);
  if (b && fxOn) HAL_GPIO_WritePin(LED_BLUE_GPIO_Port, LED_BLUE_Pin, GPIO_PIN_SET);
  else HAL_GPIO_WritePin(LED_BLUE_GPIO_Port, LED_BLUE_Pin, GPIO_PIN_RESET);

}

void mute() // <<<<<<<<<<<<<<<<<<<<<<<<<<<<<<<<<<<<エフェクト切替時、データ保存時のミュート
{
  for (uint16_t i = 0; i < BLOCK_SIZE*4; i++)
  {
    TxBuffer[i] = 0;
  }
}

void fxChange() // <<<<<<<<<<<<<<<<<<<<<<<<<<<<<<<<<<<<<<<<<<<エフェクト変更
{
  mute();
  fxDeinit();
  fxNum = (fxNumMax + fxNum + fxChangeFlag) % fxNumMax; // 最大値←→最小値で循環
  fxParamNum = 0;
  cursorPosition = 0;
  fxInit();
  fxChangeFlag = 0;
  statusStr = fxName;
}

void swProcess(uint8_t num) // <<<<<<<<<<<<<<<<<<<<<<<<<<<<<<<<<<<<<<<<<<<スイッチ処理
{
  static uint32_t swCount[10] = {}; // スイッチが押されている間カウントアップ

  switch(num)
  {
    case 0: // 左上スイッチ --------------------------------------------------------
      if (!HAL_GPIO_ReadPin(SW0_UPPER_L_GPIO_Port, SW0_UPPER_L_Pin))
      {
        swCount[num]++;
        if (swCount[num] == longPushCount) // 長押し 1回のみ動作
        {
          if (swCount[num+1] > shortPushCount) // 左下スイッチが押されている場合
          {
            swCount[num+1] = longPushCount; // 左下スイッチも長押し済み扱いにする
            saveData(); // データ保存
          }
          else
          {
            fxChangeFlag = -1;
          }
        }
      }
      else
      {
        if (swCount[num] >= shortPushCount && swCount[num] < longPushCount) // 短押し 離した時の処理
        {
          if (swCount[num+2] > shortPushCount) // 右上スイッチが押されている場合、パラメータ数値を最大値へ
          {
            swCount[num+2] = longPushCount + 1; // 右上スイッチは長押し済み扱いにする
            fxParam[fxParamNum] = fxParamMax[fxParamNum];
          }
          else
          { // エフェクトパラメータ選択位置変更 0→最大値で循環
            fxParamNum = (fxParamNumMax + fxParamNum - 1) % fxParamNumMax;
            cursorPosition = fxParamNum % 6;
          }

        }
        swCount[num] = 0;
      }
      break;
    case 1: // 左下スイッチ --------------------------------------------------------
      if (!HAL_GPIO_ReadPin(SW1_LOWER_L_GPIO_Port, SW1_LOWER_L_Pin))
      {
        swCount[num]++;
        if (swCount[num] == longPushCount) // 長押し 1回のみ動作
        {
          if (swCount[num-1] > shortPushCount) // 左上スイッチが押されている場合
          {
            swCount[num-1] = longPushCount; // 左上スイッチも長押し済み扱いにする
            saveData(); // データ保存
          }
          else
          {
            fxChangeFlag = 1;
          }
        }
      }
      else
      {
        if (swCount[num] >= shortPushCount && swCount[num] < longPushCount) // 短押し 離した時の処理
        {
          if (swCount[num+2] > shortPushCount) // 右下スイッチが押されている場合、パラメータ数値を最小値へ
          {
            swCount[num+2] = longPushCount + 1; // 右下スイッチは長押し済み扱いにする
            fxParam[fxParamNum] = fxParamMin[fxParamNum];
          }
          else
          { // エフェクトパラメータ選択位置変更 最大値→0で循環
            fxParamNum = (fxParamNum + 1) % fxParamNumMax;
            cursorPosition = fxParamNum % 6;
          }
        }
        swCount[num] = 0;
      }
      break;
    case 2: // 右上スイッチ --------------------------------------------------------
      if (!HAL_GPIO_ReadPin(SW2_UPPER_R_GPIO_Port, SW2_UPPER_R_Pin))
      {
        swCount[num]++;
        if (swCount[num] >= longPushCount/2 && (swCount[num] % (longPushCount/4)) == 0) // 長押し 繰り返し動作
        {
          fxParam[fxParamNum] = min(fxParam[fxParamNum] + 10, fxParamMax[fxParamNum]);
        }
      }
      else
      {
        if (swCount[num] >= shortPushCount && swCount[num] < longPushCount) // 短押し 離した時の処理
        {
          if (swCount[num+1] > shortPushCount) // 右下スイッチが押されている場合、パラメータ数値を中間値へ
          {
            swCount[num+1] = longPushCount + 1; // 右下スイッチは長押し済み扱いにする
            fxParam[fxParamNum] = (fxParamMin[fxParamNum] + fxParamMax[fxParamNum]) / 2;
          }
          else if (swCount[num-2] > shortPushCount) // 左上スイッチが押されている場合、パラメータ数値を最大値へ
          {
            swCount[num-2] = longPushCount + 1; // 左上スイッチは長押し済み扱いにする
            fxParam[fxParamNum] = fxParamMax[fxParamNum];
          }
          else fxParam[fxParamNum] = min(fxParam[fxParamNum] + 1, fxParamMax[fxParamNum]);
        }
        swCount[num] = 0;
      }
      break;
    case 3: // 右下スイッチ --------------------------------------------------------
      if (!HAL_GPIO_ReadPin(SW3_LOWER_R_GPIO_Port, SW3_LOWER_R_Pin))
      {
        swCount[num]++;
        if (swCount[num] >= longPushCount/2 && (swCount[num] % (longPushCount/4)) == 0) // 長押し 繰り返し動作
        {
          {
            fxParam[fxParamNum] = max(fxParam[fxParamNum] - 10, fxParamMin[fxParamNum]);
          }
        }
      }
      else
      {
        if (swCount[num] >= shortPushCount && swCount[num] < longPushCount) // 短押し 離した時の処理
        {
          if (swCount[num-1] > shortPushCount) // 右上スイッチが押されている場合、パラメータ数値を中間値へ
          {
            swCount[num-1] = longPushCount + 1; // 右上スイッチは長押し済み扱いにする
            fxParam[fxParamNum] = (fxParamMin[fxParamNum] + fxParamMax[fxParamNum]) / 2;
          }
          else if (swCount[num-2] > shortPushCount) // 左下スイッチが押されている場合、パラメータ数値を最小値へ
          {
            swCount[num-2] = longPushCount + 1; // 左下スイッチは長押し済み扱いにする
            fxParam[fxParamNum] = fxParamMin[fxParamNum];
          }
          else fxParam[fxParamNum] = max(fxParam[fxParamNum] - 1, fxParamMin[fxParamNum]);
        }
        swCount[num] = 0;
      }
      break;
    default:
      break;
  }
}

void footSwProcess() // <<<<<<<<<<<<<<<<<<<<<<<<<<<<<<<<<<<<<<<<<<<フットスイッチ処理
{
  static uint32_t footSwCount = 0; // スイッチが押されている間カウントアップ
  static float tmpTapTime = 0; // タップ間隔時間 一時保存用

  if (!HAL_GPIO_ReadPin(SW4_FOOT_GPIO_Port, SW4_FOOT_Pin))
  {
    footSwCount++;
    if (mode == TAP && footSwCount == 4*shortPushCount) // スイッチを押した時のタップ間隔時間を記録
    {
      tmpTapTime = (float)callbackCount * i2sInterruptInterval * 1000.0f;
      callbackCount = 0;
    }
    if (footSwCount == 4*longPushCount) // 長押し
    {
      if (mode == NORMAL)
      {
#if TAP_ENABLED
        mode = TAP; // タップテンポモードへ
        callbackCount = 0;
#endif
      }
      else
      {
        mode = NORMAL; // タップテンポモード、チューナーモード終了
        tapTime = 0.0f; // タップ時間リセット
      }
    }
    if (footSwCount == 12*longPushCount) // 3倍長押し
    {
      if (mode == TAP)
      {
#if TUNER_ENABLED
        mute();
        mode = TUNER; // チューナーモードへ
#endif
      }
    }
  }
  else
  {
    if (footSwCount >= 4*shortPushCount && footSwCount < 4*longPushCount) // 短押し 離した時の処理
    {
      if (mode == NORMAL) fxOn = !fxOn;
      else if (mode == TAP)
      { // スイッチを押した時記録していたタップ間隔時間をスイッチを離した時に反映させる
        if (100.0f < tmpTapTime && tmpTapTime < MAX_TAP_TIME) tapTime = tmpTapTime;
        else tapTime = 0.0f;
      }
    }
    footSwCount = 0;
  }

}

// <<<<<<<<<<<<<<<<<<<<<<<<<<<<<<<<<<<<<<<<<<<DMA用に上位16ビットと下位16ビットを入れ替える
// 負の値の場合に備えて右シフトの場合0埋めする
int32_t swap16(int32_t x)
{
  return (0x0000FFFF & x >> 16) | x << 16;
}

void mainProcess(uint16_t start_sample) // <<<<<<<<<<<<<<<<<<<<<<<<<<<<<<<<<<<<<<メイン信号処理等
{
  DWT->CYCCNT = 0; // CPU使用率計算用 CPUサイクル数をリセット

  float xL[BLOCK_SIZE] = {}; // Lch float計算用データ
  float xR[BLOCK_SIZE] = {}; // Rch float計算用データ 不使用

  for (uint16_t i = 0; i < BLOCK_SIZE; i++)
  {
     uint16_t m = (start_sample + i) * 2; // データ配列の偶数添字計算 Lch（Rch不使用）

    // 受信データを計算用データ配列へ 値を-1～+1(float)へ変更
    xL[i] = (float)swap16(RxBuffer[m]) / 2147483648.0f;

#if CLIP_DETECT_ENABLED  // 入力クリップ検出 ステータス表示
      if (xL[i] < -0.999f || xL[i] > 0.999f) statusStr = "IN CLIPPED!";
#endif
  }

  if (mode == TUNER)
  {
#if TUNER_ENABLED
    tunerProcess(xL, xR); // チューナー
#endif
  }
  else
  {
    fxProcess(xL, xR); // エフェクト処理 計算用配列を渡す
  }

  for (uint16_t i = 0; i < BLOCK_SIZE; i++)
  {
    if (xL[i] < -1.0f || xL[i] > 0.999f) // 出力クリップ検出
    {
#if CLIP_DETECT_ENABLED
      statusStr = "OUT CLIPPED!"; // 出力クリップ ステータス表示
#endif
      if (xL[i] < 0) xL[i] = -1.0f; // オーバーフロー防止
      else xL[i] = 0.999f;
    }

    uint16_t m = (start_sample + i) * 2; // データ配列の偶数添字計算 Lch（Rch不使用）

    // 計算済データを送信バッファへ 値を32ビット整数へ戻す
    TxBuffer[m] = swap16((int32_t)(2147483648.0f * xL[i]));
  }

  callbackCount++; // I2Sの割り込みごとにカウントアップ タイマとして利用
  footSwProcess(); // フットスイッチ処理
  if (mode == NORMAL)
  {
    swProcess(callbackCount % 4); // 割り込みごとにスイッチ処理するが、スイッチ1つずつを順番に行う
    cpuUsageCycleMax[fxNum] = max(cpuUsageCycleMax[fxNum], DWT->CYCCNT); // CPU使用率計算用
  }
  if (fxChangeFlag) fxChange(); // エフェクト変更 ※ディレイメモリ確保前に信号処理に進まないように割り込み内で行う

}

// <<<<<<<<<<<<<<<<<<<<<<<<<<<<<<<<<<<<<<<<<<<I2Sの受信バッファに半分データがたまったときの割り込み
void HAL_I2S_RxHalfCpltCallback(I2S_HandleTypeDef *hi2s)
{
  mainProcess(0); // 0 ～ 15 を処理(0 ～ BLOCK_SIZE-1)
}

// <<<<<<<<<<<<<<<<<<<<<<<<<<<<<<<<<<<<<<<<<<<I2Sの受信バッファに全データがたまったときの割り込み
void HAL_I2S_RxCpltCallback(I2S_HandleTypeDef *hi2s)
{
  mainProcess(BLOCK_SIZE); // 16 ～ 31 を処理(BLOCK_SIZE ～ BLOCK_SIZE*2-1)
}

void loadData() // <<<<<<<<<<<<<<<<<<<<<<<<<<<<<<<<<<<<<<<<<<<データ読み込み
{
  uint32_t addr = DATA_ADDR;
  for (uint16_t i = 0; i < fxNumMax; i++) // エフェクトデータ フラッシュ読込
  {
    for (uint16_t j = 0; j < 20; j++)
    {
      fxAllData[i][j] = *((uint16_t*)addr);
      addr += 2;
    }
  }
  fxNum = *((uint16_t*)addr);
  if (fxNum >= fxNumMax) fxNum = 0;
}

void saveData() // <<<<<<<<<<<<<<<<<<<<<<<<<<<<<<<<<<<<<<<<<<<データ保存
{
  mute();
  HAL_GPIO_TogglePin(LED_RED_GPIO_Port, LED_RED_Pin); // 処理開始 赤LED点灯切替

  eraseData(); // フラッシュ消去

  HAL_FLASH_Unlock(); // フラッシュ ロック解除

  uint32_t addr = DATA_ADDR;

  for (uint16_t j = 0; j < 20; j++) // 現在のパラメータをデータ配列へ移す
  {
    fxAllData[fxNum][j] = fxParam[j];
  }

  for (uint16_t i = 0; i < fxNumMax; i++) // フラッシュ書込
  {
    for (uint16_t j = 0; j < 20; j++)
    {
      HAL_FLASH_Program(FLASH_TYPEPROGRAM_HALFWORD, addr, fxAllData[i][j]);
      addr += 2;
    }
  }
  HAL_FLASH_Program(FLASH_TYPEPROGRAM_HALFWORD, addr, fxNum); // 保存時のエフェクト番号記録

  HAL_FLASH_Lock(); // フラッシュ ロック

  HAL_GPIO_TogglePin(LED_RED_GPIO_Port, LED_RED_Pin); // 処理終了 赤LED点灯切替
  statusStr = "STORED!"; // ステータス表示
  DWT->CYCCNT = 0; // CPU使用率計算に影響しないように、CPUサイクル数を一旦リセット
}

void eraseData() // <<<<<<<<<<<<<<<<<<<<<<<<<<<<<<<<<<<<<<<<<<<データ全消去
{
  HAL_FLASH_Unlock(); // フラッシュ ロック解除
  FLASH_EraseInitTypeDef erase;
  uint32_t error = 0;
  erase.TypeErase = FLASH_TYPEERASE_SECTORS;
  erase.Sector = DATA_SECTOR;
  erase.NbSectors = 1;
  erase.VoltageRange = FLASH_VOLTAGE_RANGE_3;
  HAL_FLASHEx_Erase(&erase, &error); // フラッシュ消去
  HAL_FLASH_Lock(); // フラッシュ ロック
}

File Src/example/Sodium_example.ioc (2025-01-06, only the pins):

Mcu.UserName=STM32F722RCTx
PA1.GPIO_Label=SW4_FOOT
PA1.Signal=GPIO_Input
PA13.Signal=SYS_JTMS-SWDIO
PA14.Signal=SYS_JTCK-SWCLK
PA15.Signal=I2S3_WS
PA4.GPIO_Label=LED_RED
PA4.Signal=GPIO_Output
PA5.GPIO_Label=LED_GREEN
PA5.Signal=GPIO_Output
PA6.GPIO_Label=LED_BLUE
PA6.Signal=GPIO_Output
PB0.GPIO_Label=SW0_UPPER_L
PB0.Signal=GPIO_Input
PB1.GPIO_Label=SW1_LOWER_L
PB1.Signal=GPIO_Input
PB11.GPIO_Label=CODEC_RST
PB11.Signal=GPIO_Output
PB12.Signal=I2S2_WS
PB13.Signal=I2S2_CK
PB15.Signal=I2S2_SD
PB4.GPIO_Label=SW2_UPPER_R
PB4.Signal=GPIO_Input
PB5.GPIO_Label=SW3_LOWER_R
PB5.Signal=GPIO_Input
PB6.Signal=I2C1_SCL
PB7.Signal=I2C1_SDA
PC10.Signal=I2S3_CK
PC12.Signal=I2S3_SD
PC6.Signal=I2S2_MCK
PH0-OSC_IN.Signal=RCC_OSC_IN
PH1-OSC_OUT.Signal=RCC_OSC_OUT

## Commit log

2020-12-21 Create KiCad files
    [Sodium.kicad_pcb, Sodium.sch, Sodium_1_bottomPCB.kicad_pcb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]
2021-03-01 Update example
    ・コーラス、フェイザー、リバーブ追加
    ・main.cをmain.cppにリネームせずに済むよう修正
    ・ディレイへのエフェクト切替の際動作停止することがあったのを修正
    [Sodium_example.ioc, fx_chorus.hpp, fx_delay.hpp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]
2021-03-23 Update example
    ・STM32CubeIDEのバージョンを1.6.0へ
    ・タップテンポ機能追加（ディレイのみ対応）
    ・チューナー機能追加（ベースは未テスト）
    ・表示パラメータ数を6個へ
    ・スイッチ操作を追加（最大値へ変更等）
2021-03-29 Update Docs
    デバッガ購入についての記事を追加
2021-04-05 Update example
    ・エフェクト解説用にブースター追加
    ・変数名等の整理
2021-04-20 Update example
    ・STM32CubeIDEのバージョンを1.6.1へ
    ・出力クリップ検出機能追加（デフォルトはオフ）
    ・BOOSTER→VOLUMEへ名称変更
    ・ステータス表示を点滅に変更
    ・データセーブ時赤LED点灯切替
2021-05-06 Update example
    ・入力クリップ検出機能追加（デフォルトはオフ）
    ・フィルタの説明文書、エフェクトの追加
2021-05-10 Update KiCad files
    [Sodium.kicad_pcb, Sodium.sch, Sodium_2_frame_Acryl8mm.kicad_pcb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]
2021-05-10 Add STM32F722RETX_FLASH.ld
2021-05-17 Update example
    ・オーバードライブ、ディストーションを追加
2021-05-24 Update example v1.3
    ・オシレータ（テスト用）追加
    ・エフェクト音は配列である必要はなかったため変更（fxL[i]→fxL）
2021-05-24 Update Docs
    ・トレモロ、フェイザーの説明を追加
2021-07-01 Update example v1.4
    ・ディレイ、コーラス、リバーブを更新（素数ディレイ削除）
2021-07-01 Update Docs
    ・ディレイの説明を追加
2021-07-06 Update Docs
    ・コーラスの説明を追加
2021-10-07 Update example v1.5
    ・オートワウを追加
2021-10-25 Update example v1.6
    ・コンプレッサーを追加
    ・1次フィルタのカットオフ周波数誤差を改善
2021-11-02 Update Docs
    ・1次フィルタの説明を更新
2021-11-04 Update Docs
    ・コンプレッサーの説明を追加
2023-11-11 Update Docs
    アップサンプリング・ダウンサンプリングの説明を追加
2025-01-06 Update example v1.8
    DMAに使う配列をDTCMRAM領域に明示的に配置
2025-03-01 Update example v1.9
    fx_upsampling.hppを修正
    [fx_upsampling.hpp]
